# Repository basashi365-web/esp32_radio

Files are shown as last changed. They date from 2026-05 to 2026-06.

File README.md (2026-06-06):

# ESP32 Radio

`esp32_radio` は、完成済みの `pi_radio` を小型ESP32-S3機へ派生させるためのネットラジオ実験プロジェクトです。

目標は、ESP32-S3 + MAX98357A I2Sアンプで WNYC / BBC / ABC のニュース・トーク局を再生し、後段でOLED表示、KY-040ロータリー操作、Wi-Fi設定画面を追加できる設計にすることです。

## 現在の状態

- PlatformIO初期ファームウェア実装済み。COM24へ書き込み、ESP32-S3 / PSRAM / OLED / Wi-Fi / WNYC音出しまで実機確認済み。
- GitHub repository: https://github.com/basashi365-web/esp32_radio
- 第一候補ライブラリは `schreibfaul1/ESP32-audioI2S`。
- ESP32-S3はPSRAM付きボードを前提にする。今回使う実物基板は写真上で `ESP32-S3-WROOM-1 N16R8` と確認済み。
- スピーカーは購入済みの 2インチ級 / 53mm / 4Ω / 3W フルレンジスピーカーを使う。
- 表示器は `pi_radio` と同じ GM009606v4.3 OLED を使い、`SSD1306 128x64 / I2C 0x3C` として扱う方針。
- 基板・周辺部品の共有写真は `D:\data\codex\shared_assets\hardware\esp32_radio\20260601_board_photos` に保存済み。
- MAX98357AとのI2S接続、候補局URL、OLED/ロータリー追加方針、Wi-Fi設定方式を調査済み。
- MAX98357Aは `VIN=5V`、`SD/MODE=3.3V` で音出し確認済み。GAINはオープンのまま。
- OLEDはI2C `0x3C` で検出済み。FreeSans系フォントの局名/音量表示を採用済み。
- KY-040は回転で音量、短押しで選曲。常用版は WNYC / BBC / ABC の3局トグル。
- 友人へ渡す将来構想として、ESP32-S3のUSB MSC設定モードで `WIFI.TXT` / `STATIONS.TXT` をPCから編集できる方式を後段候補にする。
- `pi_radio` との差分は、Linux/mpv/systemd/NetworkManagerではなく、ESP32ファームウェア単体で再生・操作・設定保存を行う点。

## 主要ドキュメント

- `docs/esp32_i2s_radio_research.md`: ESP32-S3 + MAX98357Aネットラジオの前例調査、リスク、最小実験手順。
- `docs/hardware.md`: 想定ハードウェアと部品選定。
- `docs/wiring.md`: 初期配線案。
- `docs/setup.md`: 次回の最小実験セットアップ入口。
- `docs/troubleshooting.md`: 実装前に想定している失敗パターン。
- `docs/development_notes.md`: 継続作業メモ。
- `docs/usb_msc_config_plan.md`: USB接続でTXT設定を編集する将来構想。

## 最小実験方針

1. PSRAM付きESP32-S3ボードを確認する。
2. MAX98357AをI2S 3線で接続する。
3. 53mm / 4Ω / 3W フルレンジスピーカーを `SPK+` / `SPK-` に接続する。
4. `ESP32-audioI2S` の初期スケッチでWNYC MP3直ストリームを再生する。
5. OLEDへ大きい局名、中サイズの音量、小さい `tuning...` / `stream ok` / `stream lost` を出す。
6. KY-040で音量変更と選曲を行う。
7. 友人配布向けには、Web設定画面またはUSB MSC TXT設定モードを後段で検討する。

## 参考元

- `pi_radio`: Raspberry Pi 3B+ + USB DAC/PAM8403で完成済みの親プロジェクト。
- `schreibfaul1/ESP32-audioI2S`: ESP32-S3 + I2S DAC/amp向けの第一候補ライブラリ。
- `Edzelf/ESP32Radio-V2`: 完成型ESP32ラジオUI/設定機能の参考。

## 注意

- Wi-Fi SSID/passwordなどの秘密情報はこのrepoに入れない。
- HLS/AAC局はPC上で音声検出できても、ESP32実機での再生は未確認。
- PSRAMなしESP32-S3での動作は前提にしない。

## Wake Sound

- KY-040長押し停止から復帰するとき、OLED下段に `wake...` を出し、SPIFFS上の `data/wake.m4a` を音量15で短く鳴らす。
- 音源は `D:\data\codex\shared_assets\sound_packs\skysea_sound_pack\reserve_notice.m4a` を採用した。
- 効果音ファイルを更新した場合は、通常の `pio run -t upload` に加えて `pio run -t uploadfs` も実行する。
- 2026-06-02時点では `pi_radio` のスピーカーを流用中。注文済みスピーカー到着後、起動時音量と復帰効果音音量を再調整する。

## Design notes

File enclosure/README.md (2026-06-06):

# ESP32 Radio Enclosure

`esp32_radio_compact.scad` is a first compact enclosure draft for the arrived
53 mm speaker.

## Layout

Front face, left to right:

1. KY-040 knob
2. 53 mm full-range speaker
3. SSD1306 128x64 OLED

The initial outside size is `145 x 78 x 48 mm`. This keeps the radio compact
while leaving room for the speaker depth, OLED board, KY-040 body, ESP32-S3,
MAX98357A, and wiring.

## Parts

- Front shell: set `part_mode = 1;`
- Back cover: set `part_mode = 2;`
- Preview both: set `part_mode = 0;`

## Measure Before Final Print

Tune these parameters after checking the actual parts:

- `speaker_outer_d`: actual speaker outside diameter
- `speaker_cutout_d`: full round opening diameter; current draft uses `47`
- `speaker_grille_enabled`: keep `false` when no protective grille is needed
- `speaker_mount_holes_enabled`: keep `false` when using the rear support ring
- `speaker_screw_circle_d`: speaker screw pitch circle
- `speaker_screw_hole_d`: screw hole diameter
- `encoder_shaft_hole_d`: knob shaft hole
- `encoder_mount_spacing`: KY-040 board mounting pitch
- `oled_window_w` / `oled_window_h`: visible OLED window
- `oled_board_w` / `oled_board_h`: OLED PCB size
- `oled_screw_spacing_x` / `oled_screw_spacing_y`: OLED mounting holes

## Print Notes

- Print the front shell face down if the printer handles bridge holes cleanly.
- Print the back cover flat.
- First print a thin front-panel-only test or use slicer preview to confirm the
  knob, speaker, and OLED positions before committing to a full enclosure.
- Keep Wi-Fi credentials and local configuration outside public CAD/docs.

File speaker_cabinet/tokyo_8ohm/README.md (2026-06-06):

# Tokyo Cone 8 Ohm Speaker Cabinet

This folder stores the cabinet work for the Tokyo Cone F12E28A01-1 oval speaker.

## Speaker

- Model: F12E28A01-1
- Type: 30 x 70 mm oval speaker
- Impedance: 8 ohm
- Use here: low-profile ESP32 radio integrated cabinet

## Main Files

- `esp32_radio_low_profile_integrated.scad`
- `esp32_radio_low_profile_front_shell.stl`
- `esp32_radio_low_profile_back_cover.stl`
- `esp32_radio_low_profile_front_layout.png`
- `datasheets/F12E28A01-1_speaker_datasheet.pdf`

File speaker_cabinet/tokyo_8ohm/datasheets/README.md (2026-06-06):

# Speaker Datasheets

This folder stores datasheets for speakers used while designing the ESP32 radio speaker cabinet.

## F12E28A01-1

- File: `F12E28A01-1_speaker_datasheet.pdf`
- Original downloaded file: `C:\Users\yuko\Downloads\スピーカー仕様書F12E28A01-1.pdf`
- Stored on: 2026-06-04
- Use: reference for the 4 ohm speaker cabinet dimensions and acoustic notes.

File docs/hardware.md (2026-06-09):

# Hardware Notes

## 目的

`esp32_radio` の初期実験では、Raspberry Piを使わずにESP32-S3単体でネットラジオを鳴らせるかを確認する。

## 初期候補

| 部品 | 用途 | 状態 |
|---|---|---|
| ESP32-S3-WROOM-1 N16R8 開発ボード | Wi-Fi受信、デコード、I2S出力 | 実物写真確認済み |
| MAX98357A I2S Class-D mono amp | I2S DAC内蔵アンプ | 初期音声出力 |
| 2インチ級 / 53mm / 4Ω / 3W フルレンジスピーカー | 音声出力 | 購入済み。MAX98357Aの初期実験用 |
| 5V USB電源 | ESP32-S3とアンプ給電 | 電流余裕を確認 |
| GM009606v4.3 OLED | 状態表示 | Phase 2以降。`pi_radio` と同じ表示器 |
| KY-040ロータリーエンコーダ | 音量/局切替 | Phase 3以降 |

## 18650電池化の手持ち候補

2026-06-06に、手持ち部品写真から以下を電池駆動の試作候補として選ぶ。

| 部品 | 写真上の識別 | 用途 | 判断 |
|---|---|---|---|
| XL6009E1昇圧モジュール | `XLSEMI XL6009E1`、青基板、可変抵抗付き | 18650の3V台を5Vへ昇圧 | 手持ち昇圧モジュールがこれ1個のため試作に使う。ESP32接続前に必ずテスターで5.0V前後へ調整する |
| 緑TP4056 USB-C基板 | `4056E`、`DW01A`、`8205A`、`B+` / `B-` / `OUT+` / `OUT-` 表記 | 1S Li-ion充電と保護出力 | 青TP4056より良い候補。保護IC付きに見え、電池端子と負荷端子が分かれているため試作ではこちらを使う |
| 青TP4056 micro USB基板 | `TP4056`、`4056E`、`BAT+` / `BAT-` 表記 | 1S Li-ion充電 | 充電専用基板に見える。保護付き18650を使う場合以外は今回の内蔵試作では優先しない |

この構成はpower pathではない。まずは「電源OFFで充電し、使用時は充電USBを外す」運用で試す。充電しながら常用する完成版にする場合は、load sharing / power path対応の1S充電昇圧モジュールを別途検討する。

## 18650電池化の購入済み候補

2026-06-06に、AliExpressで1S Li-ion用の充放電統合モジュールを購入した。到着予定は2026-06-10から2026-06-12。

| 部品 | 用途 | 状態 | 注意 |
|---|---|---|---|
| 1S Li-ion充放電統合モジュール Type-C / 5V 2A | 18650充電、5V昇圧、充電しながらの放電 | 5個購入済み。到着予定 2026-06-10から2026-06-12 | 通常18650では4.2V充電設定で使う。50mA未満の軽負荷で出力OFFになる仕様のため、stopped待機中の挙動を実測する |

購入時スクリーンショットと仕様メモは共有資産へ保存した。

- `D:\data\codex\shared_assets\hardware\esp32_radio\20260606_battery_power_module`

## 実物写真

今回使う基板・周辺部品のトリミング済み写真は、他プロジェクトからも参照できる共有フォルダに保存した。

- `D:\data\codex\shared_assets\hardware\esp32_radio\20260601_board_photos`
- 元写真: `C:\Users\yuko\Desktop\FTP\20260601_*.jpg`
- 共有用写真: ESP32-S3 N16R8表裏、MAX98357A表裏、I2C OLED表裏、KY-040、コンタクトシート。
- 完成写真: `D:\data\codex\shared_assets\hardware\esp32_radio\20260607_completed_battery_radio`

ESP32-S3基板のモジュール刻印は写真上で `ESP32-S3-WROOM-1 N16R8` と読める。以前の Freenove ESP32-S3 Cam とは別個体として扱う。

## 完成後の筐体改善メモ

- 電源スイッチ穴は実機では超音波カッターで後加工した。次回の3Dプリント筐体では、電源スイッチ位置を確定して最初から穴を入れる。
- USB充電口も次回の3Dプリント筐体で最初から穴を入れる。現行TP4056のUSB-C、または将来の1S Li-ion充放電統合モジュールのType-C入力へアクセスできる位置にする。
- OLED右下がスピーカー側と干渉したため、実機ではディスプレイ基板を少し切り取って逃がした。次回はOLEDをもう少し左へ寄せ、スピーカーとのクリアランスを増やす。

## 現在の運用状態

2026-06-07時点では、TP4056 + XL6009E1 + 18650構成を実稼働状態として扱う。パススルー対応の1S Li-ion充放電統合モジュール到着までは、この構成で運用する。

運用ルール:

- 充電時はラジオ電源OFF。
- 使用時は充電USBを外す。
- バッテリー残量はGPIO1分圧ADCでOLEDへ表示する。

## ESP32-S3

`ESP32-audioI2S` はPSRAMを必要とするため、PSRAM付きESP32-S3を前提にする。今回の実物写真では `ESP32-S3-WROOM-1 N16R8` の刻印を確認したため、初期実験の第一候補はこのボードにする。

推奨:

- ESP32-S3-N8R8
- ESP32-S3-N16R8
- ESP32-S3-WROOM-1-N16R8

次回確認すること:

- 実ボードの型番は写真上では `ESP32-S3-WROOM-1 N16R8`。PlatformIO/Arduino側からもFlash/PSRAM認識を確認する。
- USB/JTAGや起動ストラップと競合しないGPIO。
- ネイティブUSB Deviceを使える配線/USBポートか。

## MAX98357A

MAX98357AはI2S入力を受けるモノラルClass-Dアンプ。初期実験では1個だけ使い、左右mixまたは片ch出力で小型スピーカーを鳴らす。

注意:

- `SPK+` / `SPK-` はBTL出力で、どちらもGNDへ接続しない。
- 大音量では電流不足によるリセットや音割れが起きやすい。
- GAINとSD/MODEはまずモジュール既定で試す。

## スピーカー

購入済み:

- 2インチ級 / 53mm フルレンジスピーカー。
- 定格インピーダンス: 4Ω。
- 定格出力: 3W。
- 4個セット。

MAX98357Aは3W級のモノラルClass-Dアンプなので、初期実験の組み合わせとして適している。
最初は音量を低めにし、音割れ、ビビり、ESP32-S3のリセットが出ないか確認する。

商品画像から読み取った寸法・仕様:

| 項目 | 値 |
|---|---|
| 正面外形 | 約52.6mm |
| 直径表記 | 53mm |
| 側面幅表記 | 約39.4mm |
| 側面高さ表記 | 約28.5mm |
| 高さ表記 | 30mm |
| 形状 | 円形 |
| 定格出力 | 3W |
| 定格インピーダンス | 4Ω |
| 周波数応答 | 商品画像では `170kHz` 表記。一般的な小型スピーカー仕様としては要再確認 |
| 感度 | 100 dB/W |
| 信号対雑音比 | 商品画像では `1dB` 表記。スピーカー仕様としては要再確認 |
| 高調波歪み | 商品画像では `1 TMD%` 表記。THD表記の可能性があるため要再確認 |

注意:

- スピーカーは `SPK+` / `SPK-` に接続する。
- `SPK-` をGNDへ落とさない。
- 2個のMAX98357Aでステレオ化する案もあるが、最初は1個のモノラルで十分。
- 商品ページ由来の周波数応答や歪み表記は不自然な可能性があるため、設計では4Ω / 3W / 約53mmの実装寸法を優先する。

## pi_radioから引き継ぐ考え方

- 常用局は WNYC / BBC Radio 4 / ABC NewsRadio の3局にする。NHK R1は配信方式変更と暗号化HLSの可能性があるため、操作UIには出さない。
- OLEDには局名、状態、IP、音量を出す。
- OLEDは `pi_radio` と同じ GM009606v4.3 を使い、`SSD1306 128x64 / I2C 0x3C` として扱う。
- ロータリーは回転で音量、短押しで局切替を基本にする。

移植しないもの:

- Linux systemd。
- NetworkManager。
- `shutdown -h now` による安全停止。
- USB DAC / PAM8403 構成。

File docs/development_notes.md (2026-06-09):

# Development Notes

## 2026-05-30

- `esp32_radio` を `pi_radio` 派生の本格プロジェクトとして扱う方針になった。
- 実装前に `docs/esp32_i2s_radio_research.md` を作成した。
- 最小実験の第一候補は `schreibfaul1/ESP32-audioI2S`。
- PSRAM付きESP32-S3を前提にする。
- WNYCはMP3直ストリームとして最初に試す。
- BBC Radio 4 / ABC NewsRadio / NHK R1 はPC上の `ffprobe` でHLS/AAC音声として検出できたが、ESP32実機再生は未確認。
- Web設定画面は初期実験には入れず、再生安定後の追加候補にする。
- 表示器は `pi_radio` と同じ GM009606v4.3 OLED を使う方針。`SSD1306 128x64 / I2C 0x3C` として扱う。
- 友人へ渡す将来構想として、ESP32-S3のUSB MSC設定モードでPCから `WIFI.TXT` / `STATIONS.TXT` を編集する方式を最後に試す候補へ追加した。
- スピーカーは購入済みの2インチ級 / 53mm / 4Ω / 3Wフルレンジスピーカーを使う。商品画像上の寸法は正面外形約52.6mm、直径53mm、高さ30mm。

## 次回作業入口

1. PlatformIO/Arduino側でPSRAM容量を確認する。
2. 53mm / 4Ω / 3WスピーカーをMAX98357Aへ接続する。
3. `platformio.ini` のボード/PSRAM設定が実機に合うか確認する。
4. MAX98357A + WNYC の最小再生スケッチをCOM24へ書き込む。
5. Serialログと実機結果をこのdocsへ追記する。
6. 再生とOLED/ロータリーが安定した後、USB MSC TXT設定モードを調査する。

## 2026-06-01 実機接続メモ

- ESP32-S3 N16R8 dev board はWindows上で `COM24` として見えている。COMポートは接続順で変わるため、実験前に再確認する。
- Wi-Fiは固定SSIDではなく、ローカル設定のSSID prefixで候補を絞る。
- 複数SSIDがある環境では、単純なRSSI最強ではなく、前回成功SSIDをESP32 Arduino `Preferences` に保存して次回起動時に優先する。
- 接続成功SSIDは `Preferences` namespace `wifi` / key `last_ssid` に保存する設計にする。
- 実パスワードは `include/config.local.h` のみに置き、repoやAI Docsへ入れない。
- PlatformIO最小プロジェクトを追加した。`src/main.cpp` はPSRAM/Flash情報をSerialへ出し、SSID prefix一致候補から前回成功SSIDを優先してWi-Fi接続し、WNYCをMAX98357AへI2S出力する初期スケッチ。
- 標準PlatformIO `espressif32` では `ESP32-audioI2S` 3.4.6 が `<span>` を要求してビルド失敗したため、`pioarduino/platform-espressif32` stableへ切り替えた。
- `ESP32-audioI2S` 3.4.6 の `Audio.h` が `std::optional` を使うが `<optional>` を直接includeしていないため、`platformio.ini` の `build_flags` で `-I include` と `-include optional` を追加した。Cファイルにも同じflagが当たるため、`include/optional` にC++時だけ本物の標準ヘッダへ渡す小さなshimを置いた。
- USBケーブル交換後、`pio run -t upload` がCOM24へ成功した。低速 `upload_speed = 115200` と `PYTHONIOENCODING=utf-8` / `PYTHONUTF8=1` を使うとPlatformIOの進捗文字によるcp932例外を避けやすい。
- SerialログでESP32-S3 rev 2、Flash 16MB、PSRAM 8MBを確認した。
- Wi-Fiはprefix一致候補を見つけ、`Preferences` の前回成功SSID優先で接続成功した。
- OLEDとKY-040が接続済みになったため、初期スケッチへSSD1306 OLED表示、I2C scan、KY-040音量変更、短押し局送りを追加した。
- 実機ログでOLEDはI2C `0x3C` として検出できた。
- WNYCはSSL接続、MP3Decoder初期化、`stream ready`、MPEG-1 Layer III / 32kHz / 96kbps まで確認できた。実音声はスピーカー側で要耳確認。
- KY-040の回転で音量変更ログを確認できた。短押し局送りもログ上は動いている。
- BBC Radio 4の旧HLS URLは実機で `HTTP/1.1 410 Gone`。2026-06-02時点で見つかるnon-UK向けHLS URLへ差し替えた。
- NHK R1は候補URLでDNS失敗が一度出た。再テストが必要。
- 2026-06-02: KY-040の音量表示は素直に反応。ABC Newsへ移動したところで長時間ブロックし、その後NHKへ移ったとの実機報告あり。音出しが終わるまでHLS局は局送り対象から外し、WNYCだけを有効化する。
- スピーカーから音が出ていない。GAINはオープンで問題なし。SD/MODEもオープンだったため、まずSD/MODEを3.3Vへ接続して強制ONで確認する。
- OLED表示は、局名を上半分の大きい文字、音量を中くらい、ストリーム/IP状態を最下段の小さい文字に変更した。
- OLEDの局名/音量表示をAdafruit GFXのFreeSans系フォントへ変更した。白黒OLEDなので本当のアンチエイリアスはないが、デフォルトフォントより読みやすい字形にする。
- 最下段は `bitrate...` などの内部イベント名を出さず、再生準備ができたら `stream ok` を出す。
- WNYCが時々無音になるとの報告。ログ上は `slow stream, dropouts are possible` が出ていたため、ストリーム停止/再接続とアンプ側無音を切り分ける必要がある。`audio.isRunning()` を監視し、停止が続く場合はOLED下段に `stream lost`、再接続時は `stream ok` を出す。
- OLEDフォントはFreeSans系で確定。最下段は内部イベント名を出さず、人間向けの `tuning...` / `stream ok` / `stream lost` / `not tested` だけにする。
- KY-040クリックは選曲操作にする。未検証局は局名表示だけ切り替え、再生は開始しないことでABC/NHKの長時間ブロックを避ける。
- BBC Radio 4はBBCだけ有効化した実機テストで音出しOK。WNYCのMP3直ストリームだけでなく、少なくともBBCのHLS入口はESP32-S3 + ESP32-audioI2S + MAX98357A構成で再生できる。
- 次は同じ手順でABC NewsRadioだけを追加有効化し、フリーズ/無音/`stream ok` を確認する。
- ABC NewsRadioは `stream ok` までは到達。ただし実音声は出なかった。深夜帯の無音、局側の番組状態、またはHLS/AACの音声処理差を疑い、後日別時間帯でも再確認する。
- 次はNHK R1を追加有効化し、同じく `stream ok` と実音声を切り分ける。
- ABC表示中にクリックすると、次局へ移るまで約10秒停止する。NHK R1は `tuning...` で止まり、その後クリック/音量操作も効かない完全フリーズへ進んだ。初期常用版ではABC/NHKを再び無効化し、WNYC/BBCだけを有効局にする。
- ABC/NHKは夜間の局側状態だけでなく、`audio.connecttohost()` またはHLS処理がブロックしてUIループを止めるリスクがある。再検証は別時間帯に、まずSerialログを取りながら1局ずつ行う。
- 2026-06-02朝にABC/NHKを再度有効化して実機確認した。ABCは音が出ず、10秒以上フリーズする。NHKも音が出ず、最終的に完全フリーズする。時間帯だけの問題ではなく、ESP32側の接続/デコード処理がUIループを巻き込む問題として扱う。
- 常用版はWNYC/BBCのみ有効、ABC/NHKは `not tested` 表示だけに戻す。ABC/NHKを再検証する場合は、同期的な `audio.connecttohost()` を直接UIループで呼ばない設計、またはタイムアウト/別タスク化を先に検討する。
- 2026-06-02朝の再調査で、esp32_radioに入れていたABC URL `2038310/.../master.m3u8` はPC側でも404だった。pi_radio実績のABC URL `2038311/.../index.m3u8` は `streaming.abc-cdn.net.au` へリダイレクトし、AAC音声として検出できた。
- ESP32実機ではABCをmaster playlistではなくAAC-LC 44.1kHz monoのmedia playlist `https://mediaserviceslive.akamaized.net/hls/live/2109425/newsradio/v0-221.m3u8` へ直結したところ音出し成功。WNYC/BBC/ABCは常用局として有効化する。
- `audio.setConnectionTimeout(1000, 2500)` を追加し、`connecttohost()` の経過時間をSerialへ出すようにした。これ以降、ABC/NHKを触っても全体フリーズは出ず、選局操作はスムーズになった。
- NHK R1はpi_radio実績URL `https://simul.drdi.st.nhk/live/3/joined/master.m3u8` がPC側でAAC/HLSとして検出できるが、media playlistに `EXT-X-KEY:METHOD=AES-128` が含まれる。ESP32-audioI2S側で暗号化HLSが扱えない可能性があるため、現時点では常用局から外して `not tested` 扱いに戻す。
- moriya判断でNHK R1は表示にも出さず、常用版はWNYC/BBC/ABCの3局トグルにする。NHKは今後の研究対象としてdocsには履歴を残すが、操作UIからは外す。

## 音質検討メモ

- `pi_radio` と比べると `esp32_radio` は少し音が悪い気がしたが、現時点では決定的な差とは判断しない。
- 同じスピーカーを流用しているため、主な差分要因は MAX98357A、5V/GND配線、電源安定性、ESP32側のWi-Fi/デコード負荷、I2S処理まわりと考える。
- MAX98357Aの `SD/MODE` を3.3Vへ接続したら音が出た。`SD/MODE` オープンは今回の無音原因だった可能性が高い。
- `GAIN` はオープンでよい。音割れやノイズが出た場合だけ、GAIN設定、ソフト音量、電源容量を見直す。
- `PCM5102A + PAM8403` は音質改善候補。ただし部品、配線、電源、筐体内スペース、コストが増え、今回はチリツモになるため保留する。
- 現時点では MAX98357A 構成を採用継続する。
- 音質改善はまず、筐体、スピーカー固定、5V/GND配線の太さ/短さ、電源安定化、I2S配線の取り回しから見る。
- WNYCの無音化は、OLED下段表示とSerialログで `stream` 側か I2S/アンプ側かを切り分ける。`stream ok` のまま無音ならI2S/アンプ/電源側、`stream lost` や再接続表示ならネットワーク/ストリーム側を疑う。

## 通信停止/待機メモ

- スマホのテザリング利用時に消し忘れで通信し続けるのを避けるため、KY-040長押しでESP32向けの停止状態へ入る。
- 停止時は `audio.stopSong()`、`WiFi.disconnect(false)`、`WiFi.mode(WIFI_OFF)` を行い、OLEDの音量表示位置に `stopped`、下段に `wifi off` を表示する。
- 停止中は `audio.loop()` と自動リトライを止める。
- 停止中にKY-040を回す、または押すと復帰する。復帰操作そのものは音量変更や局送りには使わず、まずWi-Fi再接続と現在局の再生を試す。
- これは `pi_radio` のshutdownではなく、ESP32版の通信停止/待機機能として扱う。
- 実機で長押し停止と、KY-040を回す/押す操作による復帰が成功した。
- 2026-06-02: stoppedからの復帰時に遊びとして効果音を追加した。`skysea_sound_pack` の3候補から、短く軽い `reserve_notice.m4a` を選び、`data/wake.m4a` としてSPIFFSへ格納する。
- 復帰時はOLED下段に `wake...` を出し、効果音だけ `WAKE_EFFECT_VOLUME=15` で再生する。再生後は元の `currentVolume` に戻し、Wi-Fi再接続と現在局再生へ進む。
- SPIFFSは `board_build.filesystem = spiffs` と `pio run -t uploadfs` で書き込む。ファーム本体とは別領域なので、効果音を変えた場合は `uploadfs` も必要。

## 仮完成メモ

- 2026-06-02時点で、ESP32-S3 + MAX98357A + OLED + KY-040 による WNYC / BBC / ABC の3局トグル版はひとまず完成扱いにする。
- 現在のスピーカーは `pi_radio` のものを流用中。注文済みの 53mm / 4Ω / 3W スピーカー到着後、2026-06-05ごろを目安に音量を再調整する。
- 次回調整対象は、起動時の `AUDIO_VOLUME_INITIAL` と、stopped復帰効果音の `WAKE_EFFECT_VOLUME`。現時点の復帰効果音は volume 15。

## 18650電池化メモ

- 2026-06-06: 18650内蔵案を検討した。2S直列は電源余裕があるが、2セル用の充電制御/BMSが手元にないため今回は保留する。
- 1S2P並列は心理的に避けたい方針。今回の試作では使わない。
- 手持ち部品では、緑TP4056 USB-C基板とXL6009E1昇圧モジュールを候補にする。緑TP4056は写真上で `B+` / `B-` / `OUT+` / `OUT-` があり、`DW01A` / `8205A` 保護回路付きに見えるため、青TP4056より今回向き。
- この構成はpower pathではない。充電しながら鳴らす常用は避け、まずは電源OFFで充電、使用時は充電USBを外す運用で試す。
- OLEDへ電池残量%を出す場合は、昇圧後の5Vではなく18650側を抵抗分圧してADCで読む。
- 2026-06-06: 1S Li-ion充放電統合モジュール Type-C / 5V 2A をAliExpressで5個購入した。到着予定は2026-06-10から2026-06-12。購入時スクリーンショットは `D:\data\codex\shared_assets\hardware\esp32_radio\20260606_battery_power_module` に保存した。
- 商品説明上は、充電しながらの放電に対応、昇圧出力5Vから5.15V / 2A、負荷50mA未満継続で出力OFF、K端子で出力ON/OFF可能。到着後は、再生中の5V低下、USB抜き差し時の瞬断、stopped待機中の自動OFF、発熱を確認する。
- 2026-06-07: TP4056 + XL6009E1を筐体内へ配置し、デバイス動作を確認した。GPIO1へ100kΩ/100kΩ分圧を入れ、OLED右下へ `Bxx%` として18650残量目安を表示するファームウェアをCOM24へ書き込んだ。
- 電源投入時に起動しているようでもOLEDが点灯しないことがあるため、OLED初期化を3回試行し、起動後も未検出なら3秒ごとに再初期化する処理を追加した。
- バッテリー表示は実機で動作確認できた。GPIO1とGNDの間に10uFセラミックコンデンサを追加したところ、コンデンサなしに比べてADC由来の表示ふらつきがかなり減り、残量表示が実用上落ち着いた。表示更新を約7秒ごと、1%以内の変化は前回表示維持にして、OLED表示のちらつきをさらに抑える方針にした。
- 2026-06-07: バッテリー運用版として完成。USBケーブルから解放されることで、ラジオデバイスとしての使い心地がかなり良くなった。完成写真は `D:\data\codex\shared_assets\hardware\esp32_radio\20260607_completed_battery_radio` に保存した。写真上では WNYC FM / Vol 3 / battery 53% / `stream ok` が表示されている。
- 完成後の筐体改善点: 電源スイッチ部分は実機では超音波カッターで後加工して穴を開けたため、次回筐体設計では最初から電源スイッチ穴を入れる。USB充電できるように、TP4056または将来の充放電統合モジュールのUSB充電口用の穴も最初から入れる。OLED右下がスピーカー側と干渉し、実機ではディスプレイ基板を少し切り取って逃がしたため、次回はOLED位置をもう少し左へ寄せてスピーカーとの干渉余裕を取る。
- 現在の状態: パススルー対応の1S Li-ion充放電統合モジュールが届くまでは、TP4056 + XL6009E1 + 18650構成を実稼働状態として運用する。充電時はラジオ電源OFF、使用時は充電USBを外す運用を継続する。

## 記録ルール

- 実機で確認したことは、未確認仮説と分けて書く。
- Wi-Fiパスワード、トークン、APIキーは書かない。
- 放送局URLは変更される可能性があるため、確認日を書く。
- `pi_radio` から再利用した設計と、ESP32用に変えた設計を分ける。

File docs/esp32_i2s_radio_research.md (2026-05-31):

# ESP32-S3 + MAX98357A I2S Radio Research

作成日: 2026-05-30

このメモは、`pi_radio` の派生版として ESP32-S3 + MAX98357A による小型ネットラジオ `esp_radio` を設計するための事前調査である。まだ実装は始めない。前例、部品構成、リスク、最小実験手順を整理する。

## 結論

- 最小実験の第一候補は `schreibfaul1/ESP32-audioI2S`。
- ESP32-S3は PSRAM付きボードを前提にする。特に `ESP32-S3-N16R8` や `N8R8` のような PSRAM搭載品が安全。
- MAX98357Aは I2S 3線 `BCLK` / `LRC` / `DIN` と電源/GNDだけで音が出せる。モノラルアンプなので、まずは1個で十分。
- スピーカーは購入済みの2インチ級 / 53mm / 4Ω / 3Wフルレンジスピーカーを使う。
- `WNYC` はMP3直ストリームなので最も実験向き。
- `BBC Radio 4`、`ABC NewsRadio`、`NHK R1` はHLS/AACとしてPC上では音声検出できたが、ESP32実機では `m3u8` リダイレクト、TLS、バッファ、地域/配信URL変更のリスクがある。
- Web設定画面は最初から本格実装しない。最初は固定SSID + 固定局URLで音を出し、次に簡易AP/設定保存、最後にWeb UIを検討する。
- 友人へ渡す段階では、ESP32-S3のUSB MSC設定モードでPCから `WIFI.TXT` / `STATIONS.TXT` を編集できる方式を後段候補にする。
- `Edzelf/ESP32Radio-V2` は完成度の高いラジオアプリの参考にはなるが、最小実験の土台としては大きい。`esp_radio` では `ESP32-audioI2S` を使った薄い実装から始める方が `pi_radio` の派生として管理しやすい。

## 調査対象

### schreibfaul1/ESP32-audioI2S

リポジトリ:

- https://github.com/schreibfaul1/ESP32-audioI2S
- Wiki: https://github.com/schreibfaul1/ESP32-audioI2S/wiki

確認した内容:

- ESP32、ESP32-S3、ESP32-P4対応。
- PSRAM最小2MBが必要と明記されている。
- 外部DACが必要で、MAX98357Aがテスト済みDACに含まれる。
- 対応codecは MP3、AAC、AAC+、WAV、FLAC、Vorbis、M4A、Opus。
- `pls`、`m3u`、`asx`、`m3u8` プレイリストを認識するとされる。
- Wi-Fi、SD、SD_MMC、SPIFFS、FFatが音源に使える。
- サンプルは `audio.setPinout(I2S_BCLK, I2S_LRC, I2S_DOUT)` でI2Sピンを指定し、`audio.connecttohost(url)` でストリームへ接続する。

評価:

- `esp_radio` の最小実験に向く。
- MAX98357Aと直接組み合わせやすい。
- HLS/AACまで試せる可能性がある。
- PSRAM必須なので、手元ボードの型番確認が最初の関門。

### Edzelf/ESP32Radio-V2

リポジトリ:

- https://github.com/Edzelf/ESP32Radio-V2

確認した内容:

- 旧 `ESP32-Radio` の新バージョン。
- I2S出力と SP/DIF 出力に対応。
- `config.h` でコンパイル時設定を行う。
- `data` ディレクトリのアップロードが必要。
- SDカード対応は experimental。
- 2024-10-17にESP32-S3実験対応が入っている。
- `DEC_HELIX` 系を選ぶとMP3/AACのソフトウェアデコード + I2S出力構成になる。
- OLED、TFT、Nextion、ロータリーエンコーダ、MQTT、Web設定など、完成品ラジオ寄りの機能を多く持つ。

評価:

- 完成形のUI、設定、Web画面、ロータリー入力、プリセット管理の参考にする価値が高い。
- 一方で、最初の `音が出るか` 実験には大きすぎる。
- `esp_radio` の第一段階では採用せず、第二段階以降の設計参考にする。

### Edzelf/ESP32-Radio

リポジトリ:

- https://github.com/Edzelf/ESP32-Radio

確認した内容:

- README上でV2の利用が推奨されている。
- 古い版はVS1053 + TFT中心の構成。
- MP3/Ogg、`.m3u`、最大320kbps、Web設定、内蔵Webサーバ、MQTT、シリアル、IR、ロータリー、タッチ入力などの機能がある。

評価:

- 旧版は設計思想と機能一覧の参考に留める。
- 新規派生の直接ベースにはしない。

## PSRAM付きESP32-S3が必要か

必要と考える。

理由:

- `ESP32-audioI2S` は現行README/Wikiで PSRAM必須を明記している。
- WebラジオではWi-Fi受信、HTTP/HLS処理、codec decode、I2S出力を同時に行うため、バッファ不足が音切れやクラッシュに直結する。
- `pi_radio` と違い、ESP32側ではLinux/mpvの大きな余裕がない。

推奨:

- 最小: ESP32-S3 + PSRAM 2MB以上。
- 推奨: ESP32-S3 + PSRAM 8MB以上。
- 候補表記: `ESP32-S3-N8R8`、`ESP32-S3-N16R8`、`ESP32-S3-WROOM-1-N16R8` など。

確認方法:

- 購入ページや基板シルクで PSRAM有無を確認する。
- PlatformIO/Arduinoの起動ログで `PSRAM` 検出を確認する。
- 実験スケッチで `ESP.getPsramSize()` を表示する。

## MAX98357AとのI2S配線

MAX98357A側の主要ピン:

| MAX98357A | 役割 | ESP32-S3側 |
|---|---|---|
| VIN | 電源 | 5V推奨。小音量実験なら3.3Vでも動く場合がある |
| GND | GND | GND共通 |
| BCLK | I2S bit clock | 任意の出力可能GPIO |
| LRC / LRCLK / WS | I2S left/right clock | 任意の出力可能GPIO |
| DIN | I2S audio data in | 任意の出力可能GPIO |
| SD / MODE | shutdown / L/R/mono選択 | まずはモジュール既定。必要なら抵抗でmono平均を確認 |
| GAIN | gain設定 | まずは未接続またはモジュール既定 |
| SPK+ / SPK- | スピーカー出力 | 4Ω以上の小型スピーカー。GNDへ接続しない |

初期配線案:

| 信号 | ESP32-S3 GPIO案 | 備考 |
|---|---:|---|
| I2S_DOUT -> DIN | GPIO4 | `ESP32-audioI2S` Wiki例に合わせた案 |
| I2S_BCLK -> BCLK | GPIO5 | 同上 |
| I2S_LRC -> LRC | GPIO6 | 同上 |
| OLED SDA | GPIO8 | 仮。実ボードの空きピンに合わせて変更 |
| OLED SCL | GPIO9 | 仮。実ボードの空きピンに合わせて変更 |
| Rotary A | GPIO10 | 仮。割り込み入力に使いやすいピン |
| Rotary B | GPIO11 | 仮 |
| Rotary SW | GPIO12 | 仮。内部pull-up利用想定 |

注意:

- ESP32-S3は基板ごとに使えないピンやUSB/JTAG/PSRAM/Flashに近い注意ピンがある。実ボード型番確定後にピン表で再確認する。
- MAX98357Aのスピーカー出力はBTL出力なので、`SPK-` をGNDへ落とさない。
- 大音量では電流が増えるため、スピーカー駆動は5V電源に余裕を持たせる。
- 音割れやノイズが出る場合、GAINを下げる、音量初期値を下げる、BCLK/LRC/DINの配線を短くする。
- 今回の初期スピーカーは2インチ級 / 53mm / 4Ω / 3Wフルレンジ。商品画像上の寸法は正面外形約52.6mm、直径53mm、高さ30mm。MAX98357Aの3W級出力に合うが、最初は音量を低めにする。

## 対応ストリーム形式

`ESP32-audioI2S` ベースで期待できる形式:

| 形式 | 期待度 | 備考 |
|---|---|---|
| MP3直ストリーム | 高 | 最小実験の第一候補 |
| AAC直ストリーム | 高 | ESP32-S3ではAAC+ SBR/Parametric Stereoも対応表に入る |
| PLS / M3U | 中-高 | ライブラリが認識対応。ただしURL解決の癖は実機確認が必要 |
| M3U8 / HLS | 中 | ライブラリ上は認識対象。放送局側のTLS/リダイレクト/セグメント条件で失敗する可能性 |
| Ogg/Vorbis | 中 | 対応表にはあるが、Vorbisはビットレート条件あり |
| FLAC | 低-中 | 対応するが、ネットラジオ用途では負荷・帯域が重い |
| Opus | 中 | 対応表にはあるが、局候補では優先しない |

## 局URLの再生可能性

`pi_radio/config/stations.json` の候補URLをPC上の `ffprobe 8.1.1` で確認した。これは `ESP32で再生できる保証` ではなく、2026-05-30時点でURLが音声ストリームとして見えるかの確認である。

| 局 | URL | PC上の検出結果 | ESP32-S3見込み |
|---|---|---|---|
| WNYC FM | `https://fm939.wnyc.org/wnycfm` | MP3 / 32000Hz / stereo | 最有力。最初に試す |
| BBC Radio 4 | `https://a.files.bbci.co.uk/ms6/live/3441A116-B12E-4D2F-ACA8-C1984642FA4B/audio/simulcast/hls/nonuk/audio_syndication_low_sbr_v1/cfs/bbc_radio_fourfm.m3u8` | HLS / AAC / 48000Hz / stereo | 要実機確認。HLS/TLS/地域条件に注意 |
| ABC NewsRadio | `https://mediaserviceslive.akamaized.net/hls/live/2038311/newsradio/index.m3u8` | HLS / AAC。複数variantあり | 要実機確認。variant選択とHLS処理に注意 |
| NHK R1 | `https://simul.drdi.st.nhk/live/3/joined/master.m3u8` | HLS / AAC / 48000Hz / stereo | 要実機確認。URL変更リスクあり |

最小実験の順番:

1. WNYC MP3直ストリーム。
2. BBC Radio 4 HLS/AAC。
3. NHK R1 HLS/AAC。
4. ABC NewsRadio HLS/AAC。

理由:

- WNYCは `pi_radio` でmpv/systemd再生確認済みで、ESP32側でもMP3直ストリームとして最も単純。
- HLS局は `ESP32-audioI2S` が `m3u8` を認識するとされるが、実機のメモリ、TLS、セグメント取得、リダイレクトの影響を受けやすい。

## OLED表示とロータリーエンコーダ構成

`pi_radio` ではSSD1306 128x64 OLEDとKY-040ロータリーエンコーダで、局名、音量、状態表示、短押し局切替、長押しシャットダウンを扱った。

`esp_radio` での段階案:

### Phase 1: 音だけ

- OLEDなし。
- ロータリーなし。
- 固定SSID、固定URL、Serialログのみ。
- 目的は `ESP32-S3 + MAX98357A + WNYC` で音が出ること。

### Phase 2: 表示

- `pi_radio` と同じ GM009606v4.3 OLEDをI2C接続。
- `pi_radio` では `SSD1306 128x64 / I2C 0x3C` として点灯確認済みなので、`esp_radio` でもまず同じ扱いにする。
- 表示項目:
  - 接続中/再生中/エラー
  - SSIDまたはIPアドレス
  - 局名
  - codec名
  - 音量
  - バッファ状態または再接続回数

### Phase 3: 操作

- KY-040ロータリーエンコーダ追加。
- 回転: 音量。
- 短押し: 次の局。
- 長押し: Wi-Fi設定モード、または停止/再接続。
- ESP32にはOSシャットダウンがないため、`pi_radio` の安全シャットダウン操作はそのまま移植しない。

## Wi-Fi設定方法

候補:

| 方法 | 長所 | 短所 | 推奨段階 |
|---|---|---|---|
| 固定SSID/passwordをビルド時指定 | 最小で確実 | 書き換えに再ビルドが必要。秘密情報をgitに入れない注意が必要 | Phase 1 |
| `WiFiMulti` で複数SSID | 複数環境に少し強い | まだビルド時秘密情報が残る | Phase 1.5 |
| Serial経由で初回設定 | Web UI不要 | 現地運用では不便 | Phase 2候補 |
| SoftAP + Captive Portal / WiFiManager系 | スマホから設定できる | 依存と状態管理が増える | Phase 3候補 |
| USB MSC TXT設定モード | PCとUSBケーブルで `WIFI.TXT` / `STATIONS.TXT` を編集できる。友人配布時に分かりやすい | ESP32-S3専用寄り。PCとESP32の同時書き込みを避ける設計が必要 | Phase 4候補 |
| 独自Web設定画面 + NVS/LittleFS保存 | `pi_radio` の操作感に近づく | 実装量が増え、音声再生とのリソース競合が出る | Phase 4候補 |

推奨:

- 最初は固定SSIDで実験する。
- 秘密情報は `secrets.h` や `config.local.h` に分離し、`.gitignore` 対象にする。
- 実用化段階で SoftAP + Web設定、またはESP32-S3のUSB MSC TXT設定モードを入れる。
- USB MSC方式の詳細は `docs/usb_msc_config_plan.md` に分離する。

## Web設定画面を入れるべきか

最初からは入れない。

理由:

- まず確認すべきリスクは、ESP32-S3がHLS/AAC局を安定再生できるか、MAX98357Aでノイズなく音が出るか。
- Webサーバ、DNS、設定保存、HTML配信を同時に入れると、失敗時に原因が分かりにくい。
- `pi_radio` はLinux/NetworkManager/mpvの余裕があったが、ESP32ではメモリとタスク設計が制約になる。

入れるなら:

- 音声再生が安定した後。
- 設定項目は最小限:
  - Wi-Fi SSID/password
  - 局一覧URL
  - 音量初期値
  - 再起動ボタン
  - 現在のIP/再生状態/エラー表示
- 放送局URL編集を入れる場合は、長いURLやHLS URL変更に対応できるテキスト保存方式にする。

## 既存 pi_radio との違い

| 項目 | pi_radio | esp_radio案 |
|---|---|---|
| 本体 | Raspberry Pi 3B+ | ESP32-S3 PSRAM付き |
| 再生 | `mpv` + Linux ALSA | `ESP32-audioI2S` + I2S |
| 音声出力 | USB DAC -> PAM8403/外部アンプ | MAX98357A I2S DAC内蔵アンプ |
| OS | Linux | ベアメタル/Arduino/FreeRTOS |
| サービス化 | systemd | ファームウェア常時起動 |
| Wi-Fi | NetworkManager、既知Wi-Fi保存 | NVS/LittleFS/独自設定が必要 |
| UI | OLED + KY-040確認済み | OLED + KY-040を段階追加 |
| 安全停止 | 長押しで `shutdown -h now` | 原則不要。リセット/省電力/停止操作に置換 |
| 局再生の安定性 | mpvが強い | ライブラリ・PSRAM・HLS次第 |
| 保守 | SSHでログ確認しやすい | Serialログ/OTA/Webログ設計が必要 |
| 消費電力/サイズ | 大きめ | 小型・低消費電力化しやすい |

派生方針:

- `pi_radio` の局リスト、OLED表示項目、ロータリー操作思想を再利用する。
- Linux依存の systemd、NetworkManager、安全シャットダウンは移植しない。
- `esp_radio` では「小型・単機能・ファームウェア完結」を優先する。

## リスク

- PSRAMなしボードではライブラリ要件を満たさない可能性が高い。
- HLS/AAC局はPCやPiで再生できてもESP32で安定するとは限らない。
- 放送局URLは変更される可能性がある。特にNHKとABCは直接URLの寿命に注意。
- TLS証明書、HTTPSリダイレクト、SNI、User-Agent差で失敗する可能性がある。
- MAX98357AのGAIN/SD/MODE設定によって音量、左右ch、mono mix、ノイズが変わる。
- スピーカー電源電流が足りないとリセット、音割れ、ノイズが出る。
- OLEDとロータリーを追加すると、I2C/割り込み/描画更新が音声再生ループを邪魔する可能性がある。
- Web設定画面を入れるとメモリとタスク競合が増える。

## 最小実験手順

まだ実装しないが、次回作業の入口として以下を想定する。

1. 使用するESP32-S3ボード型番を確認する。
2. PSRAM有無、Flash容量、使用不可ピンを確認する。
3. MAX98357Aを `BCLK` / `LRC` / `DIN` / `VIN` / `GND` だけで接続する。
4. PlatformIO または Arduino IDE で `ESP32-audioI2S` の最小スケッチを作る。
5. `ESP.getPsramSize()`、Wi-Fi接続、IPアドレスをSerialに出す。
6. WNYC `https://fm939.wnyc.org/wnycfm` だけを再生する。
7. 音が出たら、音量初期値を低めから上げる。
8. BBC/NHK/ABCのHLS URLを1つずつ試す。
9. 成功/失敗時のSerialログ、codec名、最後に接続したURLを記録する。
10. その後にOLED、ロータリー、Wi-Fi設定、Web設定画面の順で足す。

## 採用候補構成

初期:

- ESP32-S3 PSRAM付き開発ボード。
- MAX98357A I2S Class-D mono amp。
- 2インチ級 / 53mm / 4Ω / 3W フルレンジスピーカー。
- 5V USB電源。
- `ESP32-audioI2S`。
- 固定SSID + WNYC固定URL。

次段階:

- SSD1306/SH1106 128x64 I2C OLED。
- GM009606v4.3 OLED。`SSD1306 128x64 / I2C 0x3C` として開始。
- KY-040ロータリーエンコーダ。
- 複数局テーブル。
- NVS/LittleFS設定保存。
- SoftAP設定モード。

後回し:

- Web設定画面。
- USB MSC TXT設定モード。
- OTA。
- MQTT。
- SDカード局リスト。
- 起動音/効果音。

## 参考リンク

- `schreibfaul1/ESP32-audioI2S`: https://github.com/schreibfaul1/ESP32-audioI2S
- `ESP32-audioI2S` Wiki: https://github.com/schreibfaul1/ESP32-audioI2S/wiki
- `Edzelf/ESP32Radio-V2`: https://github.com/Edzelf/ESP32Radio-V2
- `Edzelf/ESP32-Radio`: https://github.com/Edzelf/ESP32-Radio
- Adafruit MAX98357A pinouts: https://learn.adafruit.com/adafruit-max98357-i2s-class-d-mono-amp/pinouts
- Espressif Arduino I2S API: https://docs.espressif.com/projects/arduino-esp32/en/latest/api/i2s.html
- `pi_radio` local reference: `D:\data\codex\pi_radio`

## 完了条件

- `docs/esp32_i2s_radio_research.md` に、前例、PSRAM要否、I2S配線、対応形式、局URL見込み、OLED/ロータリー構成、Wi-Fi設定、Web設定画面の要否、`pi_radio`との差分、リスク、最小実験手順が整理されている。
- 実装コードやPlatformIOプロジェクトはまだ作成しない。

## 作業後チェック

- 実装開始を示すファイルが増えていない。
- 秘密情報、Wi-Fiパスワード、APIキーが含まれていない。
- 局URLの確認結果が `PC上のffprobe確認` と `ESP32実機再生確認` で混ざっていない。
- `pi_radio` で確認済みの事実と、`esp_radio` の未確認仮説が区別されている。

## 失敗条件

- PSRAMなしESP32-S3でも確実に動くと断定している。
- HLS/AAC局を実機未確認なのに再生可能と断定している。
- Web設定画面を最小実験の必須要件にしている。
- `pi_radio` のLinux/systemd/NetworkManager前提をESP32へそのまま移植する前提になっている。

## 報告してほしい内容

- どの前例を第一候補にしたか。
- PSRAM付きESP32-S3を推奨する理由。
- 最初に試す局URL。
- 実装前に残っている主なリスク。
- 次回実装に入る場合の最初の作業入口。

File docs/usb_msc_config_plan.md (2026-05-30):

# USB MSC TXT Configuration Plan

作成日: 2026-05-30

## 目的

`esp32_radio` を友人へ渡したあと、PCとUSBケーブルで接続して `WIFI.TXT` や `STATIONS.TXT` を書き換えられる構成を将来候補にする。

初期実験ではWi-Fi SSID/passwordをコードまたはローカル専用設定ファイルに書く。再生確認ができた後、ESP32-S3のネイティブUSB Device機能を使い、設定モード時だけ小さなUSB Mass StorageとしてPCに見せる方式を検討する。

## 結論

- ESP32-S3 N16R8なら実験候補として現実的。
- ESP32-WROOM-32Eでは基本的に不可。USB端子はUSB-シリアル変換チップ経由で、PCからはCOMポートに見えるだけ。
- 最初から実装せず、音声再生、OLED表示、ロータリー操作が安定してから後段で試す。
- 安全のため、PCにUSBドライブとして見せるのは専用の設定モード中だけにする。

## 想定UX

```text
1. 電源OFF
2. 設定ボタンを押しながらUSB接続、またはロータリー長押しで設定モード起動
3. PCに `ESP_RADIO` のような小さいUSBドライブが表示される
4. `WIFI.TXT` と `STATIONS.TXT` を編集する
5. PC側で取り外し操作をする
6. ESP32-S3を再起動する
7. 起動時にTXTを読み、NVS/LittleFS側の運用設定へ反映する
```

## 設定ファイル案

### WIFI.TXT

```text
ssid=YOUR_WIFI_NAME
password: YOUR_WIFI_PASSWORD
hostname=esp-radio
```

注意:

- `WIFI.TXT` はローカル設定用で、GitHubへ入れない。
- 配布用repoには `WIFI.EXAMPLE.TXT` だけ置く。
- 実機上の設定ファイルは秘密情報なので、ログやOLEDにpasswordを出さない。

### STATIONS.TXT

```text
WNYC FM|https://fm939.wnyc.org/wnycfm
BBC Radio 4|https://example.invalid/bbc-radio-4.m3u8
NHK R1|https://example.invalid/nhk-r1.m3u8
```

注意:

- 実際の放送局URLは変わる可能性がある。
- HLS/AAC局はESP32実機で再生できるか確認してから配布候補にする。
- 1行1局、`局名|URL` の単純形式にすると、人間が編集しやすい。

## 実装方針

### Phase 1: 通常設定

- `include/config.local.h` など、git除外ファイルにWi-Fi情報を書く。
- WNYC固定URLで再生確認する。

### Phase 2: 内部保存

- NVSまたはLittleFSに設定を保存する。
- 起動時に設定がなければデフォルト局だけで起動する。

### Phase 3: USB MSC設定モード

- ESP32-S3のTinyUSB / USB MSC機能を調査する。
- FATの小さな設定領域をPCへ見せる。
- PCがマウントしている間は、ESP32側はその領域を同時に読み書きしない。
- 設定モードを抜けたあと、TXTを検証してNVS/LittleFSへ反映する。

## 競合・破損対策

USB Mass Storageは、PCがブロックデバイスとしてファイルシステムを触る。ESP32側も同時に同じ領域を読み書きすると破損リスクがある。

安全策:

- 設定モード中はラジオ再生しない。
- 設定モード中はESP32側から設定領域へ書かない。
- PC側の取り外し後、または再起動後に設定を読む。
- 読み込む前にTXT形式を検証する。
- 不正な設定なら前回の有効設定を維持する。

## OLED表示

設定モード時は、`pi_radio` と同じOLEDに状態を出す。

想定表示:

```text
USB CONFIG
EDIT TXT FILES
EJECT + RESET
```

通常起動時:

```text
ESP RADIO
WIFI...
```

設定読み込み失敗時:

```text
CONFIG ERROR
WIFI.TXT
```

## 参考

- ESP-IDF USB Device Stack / TinyUSB: https://docs.espressif.com/projects/esp-idf/en/stable/esp32s3/api-reference/peripherals/usb_device.html
- Espressif USB FAQ / USB MSC: https://documentation.espressif.com/projects/esp-faq/en/latest/software-framework/peripherals/usb.html

## 完了条件

- 初期実験では実装しない将来候補として明確に分離されている。
- WROOM-32EではなくESP32-S3 N16R8向けの案として書かれている。
- PC接続中の同時書き込みリスクと、設定モード限定の方針が明記されている。
- `WIFI.TXT` などの秘密情報をGitHubへ入れない方針が明記されている。

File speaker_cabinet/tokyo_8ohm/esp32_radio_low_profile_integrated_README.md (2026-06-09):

# ESP32 Radio Low Profile Integrated Cabinet

This draft combines the speaker cabinet and the ESP32 radio front controls into one compact enclosure.

## Layout

- Bottom: F12E28A01-1 / 30 x 70 mm oval speaker, rotated horizontally.
- Upper center: bass-reflex style port.
- Top left: 12 x 4 mm slot for the external OLED board pin header.
- Upper right: KY-040 / volume knob shaft only. The extra KY-040 mounting holes and rear landing frame are omitted.
- Inside: open space for the ESP32-S3 board and MAX98357A board. No front-side board pads are modeled.

## Dimensions

| Item | Value |
|---|---:|
| Outer size | 118 x 70 x 52 mm |
| Wall | 4.0 mm |
| Front baffle | 4.0 mm |
| Speaker opening | 66 x 26 mm rounded slot |
| OLED/header opening | 12 x 4 mm rounded slot |
| Port | 9.5 mm x 22 mm tube |
| Rear cover lip | 1.0 mm deep, 1.2 mm clearance per side |
| Front-shell screw receivers | 5.0 mm deep rectangular corner blocks |

## Files

- `esp32_radio_low_profile_integrated.scad`: OpenSCAD source.
- `esp32_radio_low_profile_front_shell.stl`: printable front shell.
- `esp32_radio_low_profile_back_cover.stl`: printable rear cover.
- `esp32_radio_low_profile_port_plug.stl`: optional port plug.
- `esp32_radio_low_profile_front_layout.png`: front layout diagram showing display, port, volume knob, and speaker positions.

## Notes

- This is intentionally shallow, but deeper than the first round-speaker draft because the F12E28A01-1 drawing shows about 39.5 mm speaker depth.
- Check speaker terminal clearance and USB plug clearance before final printing.
- Use foam tape or a thin gasket around the speaker rim.
- If the port makes voices muddy, insert the port plug.
- Speaker screw holes are disabled until the actual tab hole positions are measured on the real unit.
- The speaker opening is a plain 66 x 26 mm rounded through-slot; the previous inner alignment groove was removed.
- The KY-040 has only the center shaft hole; rear pockets and extra service openings were removed.
- The four rear-cover screw receivers are compact rectangular blocks near the rear opening, with about 3 mm of material around each screw hole.
- The OLED board is assumed to sit outside the cabinet; only its pin header enters through the 12 x 4 mm slot.
- The top/service cutouts were intentionally removed; add cable exits later only after the real board placement is fixed.
- The rear cover lip was reduced from the first PETG print: the former 0.35 mm per-side clearance was too tight for the printed front shell.

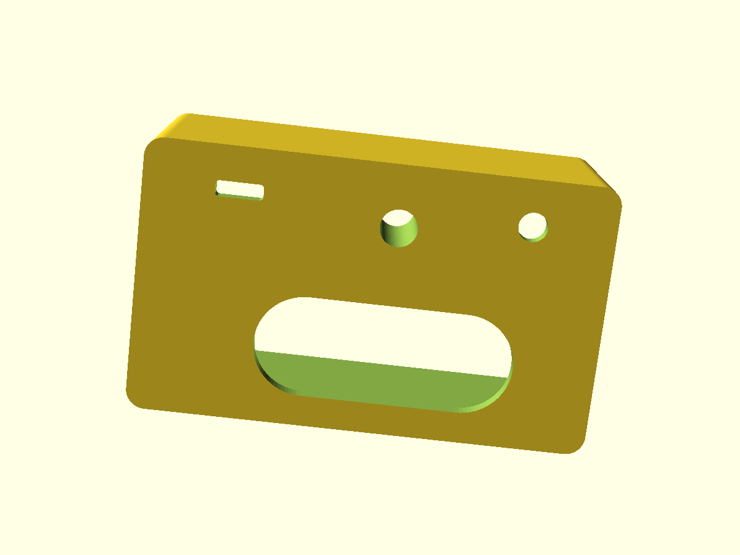
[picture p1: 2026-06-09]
speaker_cabinet/tokyo_8ohm/esp32_radio_low_profile_front_angle_preview.png

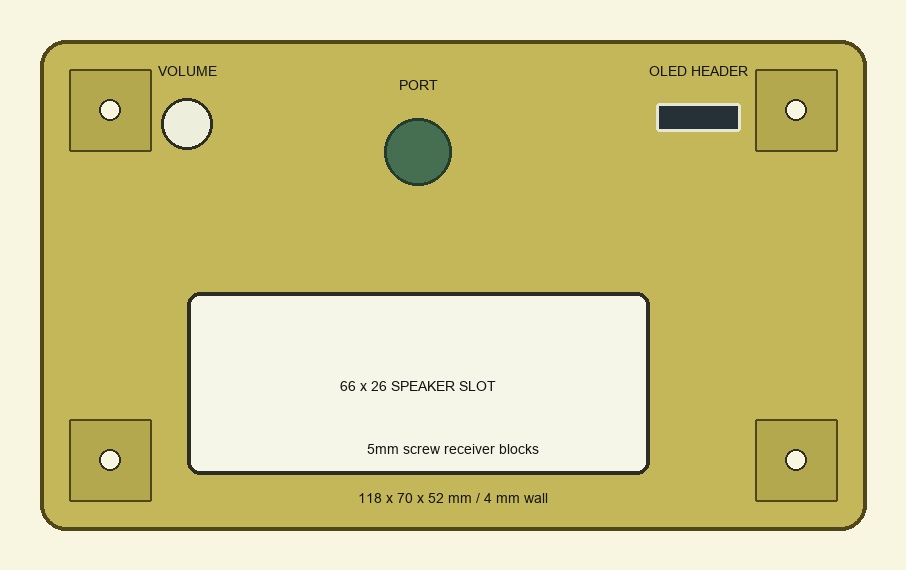
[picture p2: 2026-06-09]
speaker_cabinet/tokyo_8ohm/esp32_radio_low_profile_front_layout.png

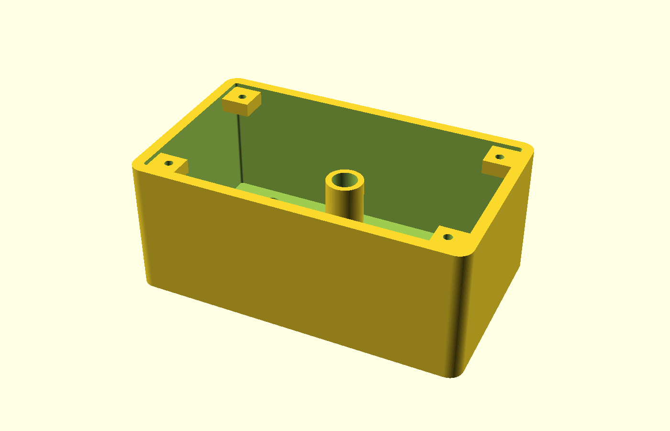
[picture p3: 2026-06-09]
speaker_cabinet/tokyo_8ohm/esp32_radio_low_profile_preview.png

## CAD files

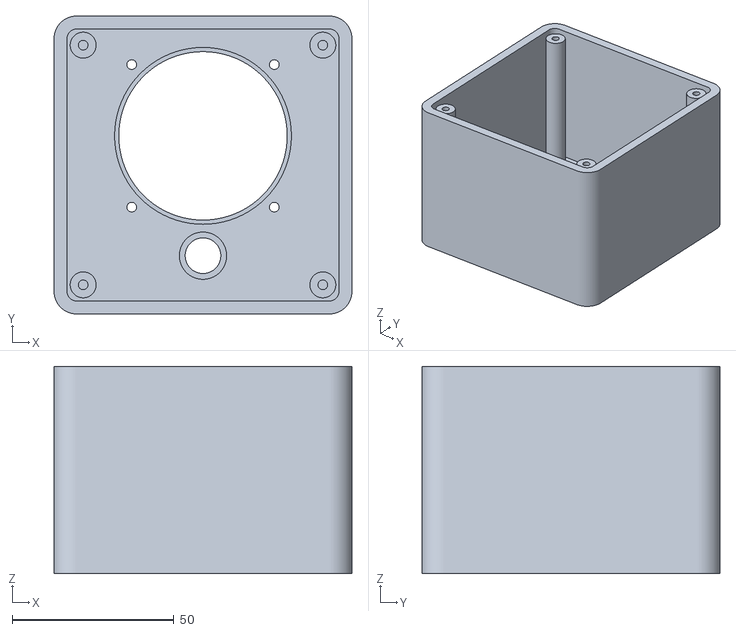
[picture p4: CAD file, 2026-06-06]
speaker_cabinet/daiso_4ohm/toilet_bgm_speaker_tuned_front_cabinet.stl
92.0 x 92.0 x 64.0

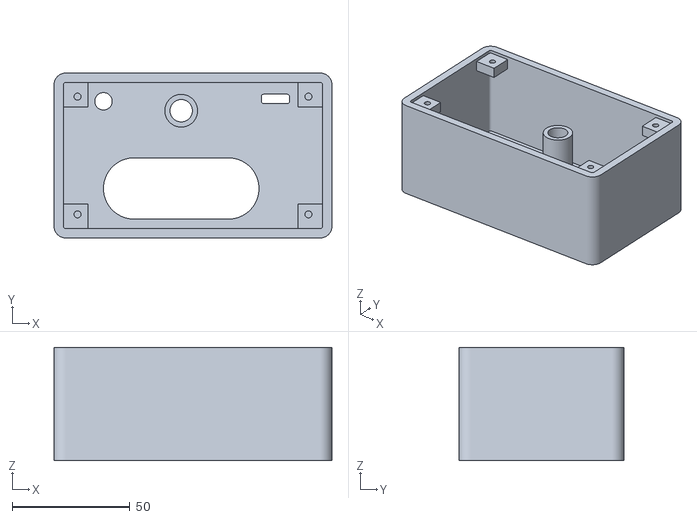
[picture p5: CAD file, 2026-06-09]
speaker_cabinet/tokyo_8ohm/esp32_radio_low_profile_front_shell.stl
118.0 x 70.0 x 48.0

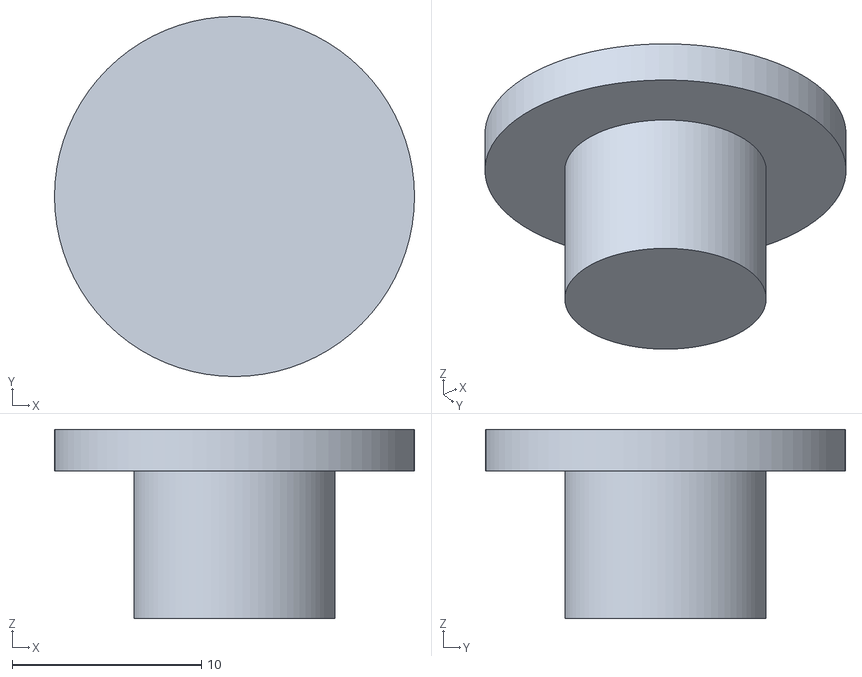
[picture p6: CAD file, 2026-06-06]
speaker_cabinet/daiso_4ohm/toilet_bgm_speaker_tuned_port_plug.stl
19.0 x 19.0 x 10.0

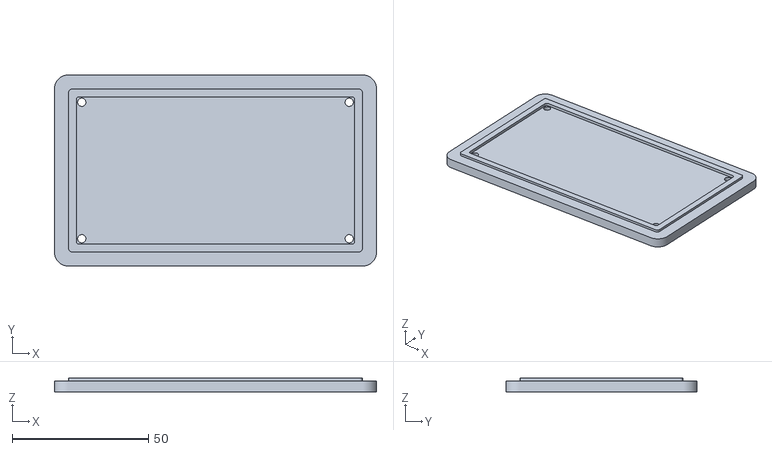
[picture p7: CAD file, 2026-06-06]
speaker_cabinet/tokyo_8ohm/esp32_radio_low_profile_back_cover.stl
118.0 x 70.0 x 5.00

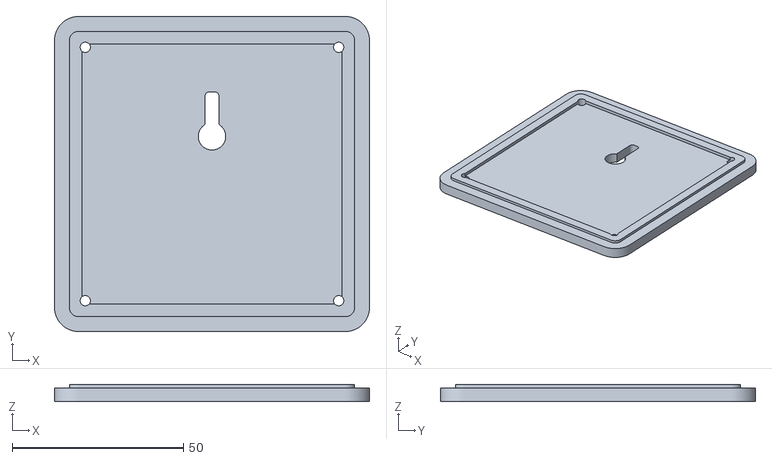
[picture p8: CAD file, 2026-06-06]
speaker_cabinet/daiso_4ohm/toilet_bgm_speaker_tuned_rear_cover.stl
92.0 x 92.0 x 5.00

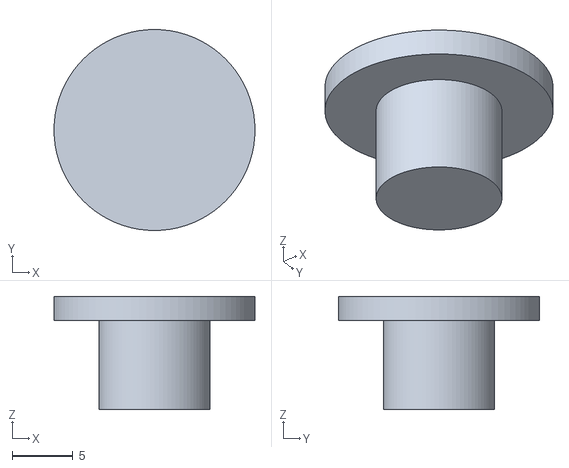
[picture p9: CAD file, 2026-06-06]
speaker_cabinet/tokyo_8ohm/esp32_radio_low_profile_port_plug.stl
16.5 x 16.5 x 9.30

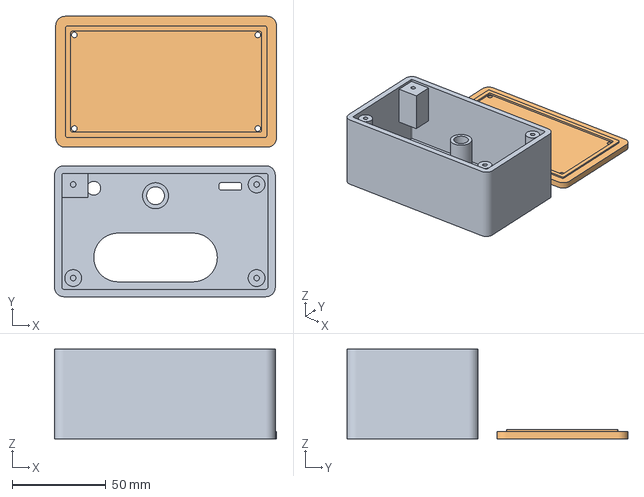
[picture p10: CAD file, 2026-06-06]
speaker_cabinet/tokyo_8ohm/TOKYO系esp32_radio_low_profile_front_shell.3mf
118.6 x 149.9 x 48.0 mm
esp32_radio_low_profile_front_shell.stl
esp32_radio_low_profile_back_cover.stl

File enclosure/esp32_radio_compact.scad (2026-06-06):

/*
  ESP32 radio compact enclosure

  Layout on the front face, left to right:
  KY-040 knob, 53 mm speaker, SSD1306 128x64 OLED.

  All dimensions are millimeters. Measure the arrived parts and tune the
  parameter block before printing the final version.
*/

$fn = 64;

// 0 = assembly, 1 = front_shell, 2 = back_cover
part_mode = 0;

// Case
case_w = 145;
case_h = 78;
case_d = 48;
wall = 2.4;
corner_r = 5;
front_th = 3.0;
back_th = 2.4;
lip_depth = 5;
lip_clearance = 0.35;

// Layout
knob_x = 23;
speaker_x = 65;
display_x = 113;
ui_y = 39;

// KY-040 / knob
encoder_shaft_hole_d = 7.4;
encoder_mount_hole_d = 3.2;
encoder_mount_spacing = 27;
encoder_body_clearance_w = 31;
encoder_body_clearance_h = 34;
encoder_body_clearance_d = 15;

// Speaker, from current project notes: outer diameter about 52.6-53 mm,
// depth about 30 mm.
speaker_outer_d = 53.4;
speaker_cutout_d = 47;
speaker_depth_clearance = 32;
speaker_screw_circle_d = 45;
speaker_screw_hole_d = 3.0;
speaker_screw_count = 4;
speaker_mount_holes_enabled = false;
speaker_grille_enabled = false;
grille_hole_d = 3.0;
grille_ring_step = 6.2;
grille_max_r = 19;

// OLED module. Defaults fit common 0.96 inch SSD1306 boards; adjust to GM009606.
oled_window_w = 26;
oled_window_h = 15;
oled_board_w = 28;
oled_board_h = 28;
oled_board_clearance_d = 8;
oled_screw_spacing_x = 23;
oled_screw_spacing_y = 23;
oled_screw_hole_d = 2.2;

// Rear cover and fasteners
cover_screw_d = 3.0;
cover_boss_outer_d = 7.2;
cover_screw_offset = 8;
usb_cutout_w = 14;
usb_cutout_h = 8;

module rounded_rect_2d(w, h, r) {
  hull() {
    translate([-(w / 2 - r), -(h / 2 - r)]) circle(r = r);
    translate([ (w / 2 - r), -(h / 2 - r)]) circle(r = r);
    translate([-(w / 2 - r),  (h / 2 - r)]) circle(r = r);
    translate([ (w / 2 - r),  (h / 2 - r)]) circle(r = r);
  }
}

module rounded_box(w, h, d, r) {
  linear_extrude(height = d)
    rounded_rect_2d(w, h, r);
}

module case_box(w, h, d, r) {
  translate([w / 2, h / 2, 0])
    rounded_box(w, h, d, r);
}

module front_panel_shape() {
  case_box(case_w, case_h, front_th, corner_r);
}

module grille_holes() {
  for (x = [-grille_max_r : grille_ring_step : grille_max_r]) {
    for (y = [-grille_max_r : grille_ring_step : grille_max_r]) {
      r = sqrt(x * x + y * y);
      if (r <= grille_max_r && r > 5) {
        translate([speaker_x + x, ui_y + y, -0.2])
          cylinder(h = front_th + 0.4, d = grille_hole_d);
      }
    }
  }
}

module speaker_mount_holes() {
  for (i = [0 : speaker_screw_count - 1]) {
    a = 360 / speaker_screw_count * i + 45;
    translate([
      speaker_x + cos(a) * speaker_screw_circle_d / 2,
      ui_y + sin(a) * speaker_screw_circle_d / 2,
      -0.2
    ])
      cylinder(h = front_th + 0.4, d = speaker_screw_hole_d);
  }
}

module front_cutouts() {
  // Knob shaft and optional KY-040 board mounting holes.
  translate([knob_x, ui_y, -0.2])
    cylinder(h = front_th + 0.4, d = encoder_shaft_hole_d);
  for (dy = [-encoder_mount_spacing / 2, encoder_mount_spacing / 2]) {
    translate([knob_x, ui_y + dy, -0.2])
      cylinder(h = front_th + 0.4, d = encoder_mount_hole_d);
  }

  // Speaker acoustic opening and grille.
  if (speaker_cutout_d > 0) {
    translate([speaker_x, ui_y, -0.2])
      cylinder(h = front_th + 0.4, d = speaker_cutout_d);
  }
  if (speaker_grille_enabled) {
    grille_holes();
  }
  if (speaker_mount_holes_enabled) {
    speaker_mount_holes();
  }

  // OLED viewing window.
  translate([display_x, ui_y, -0.2])
    linear_extrude(height = front_th + 0.4)
      rounded_rect_2d(oled_window_w, oled_window_h, 1.2);
}

module front_shell_wall() {
  difference() {
    case_box(case_w, case_h, case_d - back_th, corner_r);
    translate([wall, wall, front_th])
      case_box(case_w - wall * 2, case_h - wall * 2, case_d, max(corner_r - wall, 1));
    // Rear opening.
    translate([wall, wall, case_d - back_th - 0.2])
      case_box(case_w - wall * 2, case_h - wall * 2, back_th + 0.4, max(corner_r - wall, 1));
    // USB/service cutout on the bottom rear.
    translate([case_w / 2, case_h / 2, case_d - 20])
      rotate([90, 0, 0])
        linear_extrude(height = wall + 0.6)
          rounded_rect_2d(usb_cutout_w, usb_cutout_h, 1.2);
  }
}

module standoff(x, y, z, h, od, id) {
  translate([x, y, z])
    difference() {
      cylinder(h = h, d = od);
      translate([0, 0, -0.2])
        cylinder(h = h + 0.4, d = id);
    }
}

module internal_mounts() {
  // Speaker support ring.
  translate([speaker_x, ui_y, front_th])
    difference() {
      cylinder(h = 4, d = speaker_outer_d + 4);
      translate([0, 0, -0.2])
        cylinder(h = 4.4, d = speaker_outer_d + 0.6);
    }

  // OLED board standoffs.
  for (sx = [-1, 1]) {
    for (sy = [-1, 1]) {
      standoff(
        display_x + sx * oled_screw_spacing_x / 2,
        ui_y + sy * oled_screw_spacing_y / 2,
        front_th,
        oled_board_clearance_d,
        5.2,
        oled_screw_hole_d
      );
    }
  }

  // Encoder board clearance frame, useful as a glue/screw landing zone.
  translate([knob_x, ui_y, front_th])
    difference() {
      linear_extrude(height = 3)
        rounded_rect_2d(encoder_body_clearance_w + 4, encoder_body_clearance_h + 4, 2);
      translate([0, 0, -0.2])
        linear_extrude(height = 3.4)
          rounded_rect_2d(encoder_body_clearance_w, encoder_body_clearance_h, 1.5);
    }

  // Rear cover bosses.
  for (x = [cover_screw_offset, case_w - cover_screw_offset]) {
    for (y = [cover_screw_offset, case_h - cover_screw_offset]) {
      standoff(x, y, front_th, case_d - front_th - back_th - 1.5, cover_boss_outer_d, cover_screw_d);
    }
  }
}

module front_shell() {
  difference() {
    union() {
      front_shell_wall();
      internal_mounts();
    }
    front_cutouts();
    // Speaker rear clearance.
    translate([speaker_x, ui_y, front_th + 1])
      cylinder(h = speaker_depth_clearance, d = speaker_outer_d + 1.0);
    // OLED board rear clearance.
    translate([display_x, ui_y, front_th + 1])
      linear_extrude(height = oled_board_clearance_d + 1)
        rounded_rect_2d(oled_board_w + 1.0, oled_board_h + 1.0, 1.5);
    // Encoder body rear clearance.
    translate([knob_x, ui_y, front_th + 1])
      linear_extrude(height = encoder_body_clearance_d + 1)
        rounded_rect_2d(encoder_body_clearance_w, encoder_body_clearance_h, 1.5);
  }
}

module back_cover() {
  difference() {
    union() {
      case_box(case_w, case_h, back_th, corner_r);
      translate([wall + lip_clearance, wall + lip_clearance, back_th])
        case_box(
          case_w - wall * 2 - lip_clearance * 2,
          case_h - wall * 2 - lip_clearance * 2,
          lip_depth,
          max(corner_r - wall - lip_clearance, 1)
        );
    }
    translate([wall * 2, wall * 2, back_th - 0.2])
      case_box(
        case_w - wall * 4,
        case_h - wall * 4,
        lip_depth + 0.4,
        max(corner_r - wall * 2, 1)
      );
    for (x = [cover_screw_offset, case_w - cover_screw_offset]) {
      for (y = [cover_screw_offset, case_h - cover_screw_offset]) {
        translate([x, y, -0.2])
          cylinder(h = back_th + lip_depth + 0.4, d = cover_screw_d);
      }
    }
  }
}

if (part_mode == 1) {
  front_shell();
} else if (part_mode == 2) {
  back_cover();
} else {
  front_shell();
  translate([0, case_h + 10, 0]) back_cover();
}

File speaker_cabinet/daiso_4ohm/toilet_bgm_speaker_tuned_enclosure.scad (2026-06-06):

/*
  Larger BGM-oriented enclosure for the low-cost 53 mm / 4 ohm speaker.

  This is not a mathematically tuned hi-fi cabinet. The speaker's Thiele/Small
  parameters are unknown, so the design focuses on practical improvements:
  - larger rear air volume than the minimal box
  - stiffer front baffle
  - shallow speaker recess for a foam gasket
  - front-facing port that can be plugged if the result sounds boomy

  Print parts:
  - part_mode = 1: front cabinet
  - part_mode = 2: rear cover
  - part_mode = 3: port plug
  - part_mode = 0: all parts side by side

  All dimensions are millimeters.
*/

$fn = 80;

part_mode = 0;

// A larger cabinet for better speech/BGM fullness.
box_w = 92;
box_h = 92;
box_d = 68;
wall = 4.0;
corner_r = 7;
front_th = 4.0;
back_th = 4.0;

// Speaker.
speaker_outer_d = 53.4;
speaker_recess_d = 54.6;
speaker_recess_depth = 2.0;
speaker_cutout_d = 52.0;
speaker_body_clearance_d = 56.0;
speaker_depth_clearance = 33.0;
speaker_x = box_w / 2;
speaker_y = 55;

speaker_mount_holes_enabled = true;
speaker_screw_spacing = 44.0; // 44 mm square, about 62.2 mm diagonal.
speaker_screw_hole_d = 3.0;

// Front bass-reflex style port. Treat it as an adjustable experiment.
port_enabled = true;
port_d = 11.0;
port_len = 34.0;
port_x = box_w / 2;
port_y = 18;
port_wall = 1.8;

// Rear cover and screws.
lip_depth = 1.0;
lip_clearance = 0.35;
cover_screw_d = 3.0;
cover_boss_d = 8.0;
cover_screw_offset = 9.0;

// Rear cable exit. Face this downward if wall-mounted.
wire_slot_w = 9.0;
wire_slot_h = 4.5;

// Optional wall/keyhole slots in the rear cover.
keyhole_enabled = true;
keyhole_big_d = 8.0;
keyhole_slot_w = 4.0;
keyhole_slot_h = 13.0;

module rounded_rect_2d(w, h, r) {
  hull() {
    translate([-(w / 2 - r), -(h / 2 - r)]) circle(r = r);
    translate([ (w / 2 - r), -(h / 2 - r)]) circle(r = r);
    translate([-(w / 2 - r),  (h / 2 - r)]) circle(r = r);
    translate([ (w / 2 - r),  (h / 2 - r)]) circle(r = r);
  }
}

module rounded_box(w, h, d, r) {
  linear_extrude(height = d)
    rounded_rect_2d(w, h, r);
}

module case_box(w, h, d, r) {
  translate([w / 2, h / 2, 0])
    rounded_box(w, h, d, r);
}

module standoff(x, y, z, h, od, id) {
  translate([x, y, z])
    difference() {
      cylinder(h = h, d = od);
      translate([0, 0, -0.2])
        cylinder(h = h + 0.4, d = id);
    }
}

module speaker_mount_holes() {
  for (sx = [-1, 1]) {
    for (sy = [-1, 1]) {
      translate([
        speaker_x + sx * speaker_screw_spacing / 2,
        speaker_y + sy * speaker_screw_spacing / 2,
        -0.2
      ])
        cylinder(h = front_th + 0.4, d = speaker_screw_hole_d);
    }
  }
}

module front_openings() {
  translate([speaker_x, speaker_y, -0.2])
    cylinder(h = front_th + 0.4, d = speaker_cutout_d);

  translate([speaker_x, speaker_y, front_th - speaker_recess_depth])
    cylinder(h = speaker_recess_depth + 0.4, d = speaker_recess_d);

  if (speaker_mount_holes_enabled) {
    speaker_mount_holes();
  }

  if (port_enabled) {
    translate([port_x, port_y, -0.2])
      cylinder(h = front_th + 0.4, d = port_d);
  }
}

module rear_wire_slot() {
  translate([box_w / 2, -0.3, box_d - back_th - wire_slot_h / 2])
    rotate([90, 0, 0])
      linear_extrude(height = wall + 0.6)
        rounded_rect_2d(wire_slot_w, wire_slot_h, 1.2);
}

module cabinet_wall() {
  difference() {
    case_box(box_w, box_h, box_d - back_th, corner_r);

    translate([wall, wall, front_th])
      case_box(
        box_w - wall * 2,
        box_h - wall * 2,
        box_d,
        max(corner_r - wall, 1)
      );

    translate([wall, wall, box_d - back_th - 0.2])
      case_box(
        box_w - wall * 2,
        box_h - wall * 2,
        back_th + 0.4,
        max(corner_r - wall, 1)
      );

    rear_wire_slot();
  }
}

module port_tube() {
  if (port_enabled) {
    translate([port_x, port_y, front_th - 0.2])
      difference() {
        cylinder(h = port_len + 0.2, d = port_d + port_wall * 2);
        translate([0, 0, -0.2])
          cylinder(h = port_len + 0.6, d = port_d);
      }
  }
}

module internal_features() {
  port_tube();

  for (x = [cover_screw_offset, box_w - cover_screw_offset]) {
    for (y = [cover_screw_offset, box_h - cover_screw_offset]) {
      standoff(x, y, front_th, box_d - front_th - back_th - 1.5, cover_boss_d, cover_screw_d);
    }
  }
}

module front_cabinet() {
  difference() {
    union() {
      cabinet_wall();
      internal_features();
    }

    front_openings();

    translate([speaker_x, speaker_y, front_th + 1])
      cylinder(h = speaker_depth_clearance, d = speaker_body_clearance_d);
  }
}

module keyhole_cutout(x, y) {
  translate([x, y, -0.2])
    cylinder(h = back_th + lip_depth + 0.4, d = keyhole_big_d);

  translate([x, y + keyhole_slot_h / 2, -0.2])
    linear_extrude(height = back_th + lip_depth + 0.4)
      rounded_rect_2d(keyhole_slot_w, keyhole_slot_h, 1.2);
}

module rear_cover() {
  difference() {
    union() {
      case_box(box_w, box_h, back_th, corner_r);

      translate([wall + lip_clearance, wall + lip_clearance, back_th - 0.15])
        case_box(
          box_w - wall * 2 - lip_clearance * 2,
          box_h - wall * 2 - lip_clearance * 2,
          lip_depth + 0.15,
          max(corner_r - wall - lip_clearance, 1)
        );
    }

    translate([wall * 2, wall * 2, back_th - 0.2])
      case_box(
        box_w - wall * 4,
        box_h - wall * 4,
        lip_depth + 0.4,
        max(corner_r - wall * 2, 1)
      );

    for (x = [cover_screw_offset, box_w - cover_screw_offset]) {
      for (y = [cover_screw_offset, box_h - cover_screw_offset]) {
        translate([x, y, -0.2])
          cylinder(h = back_th + lip_depth + 0.4, d = cover_screw_d);
      }
    }

    if (keyhole_enabled) {
      keyhole_cutout(box_w / 2, box_h / 2 + 11);
    }
  }
}

module port_plug() {
  plug_len = 8;
  grip_d = port_d + 8;

  union() {
    cylinder(h = plug_len, d = port_d - 0.4);
    translate([0, 0, plug_len - 0.2])
      cylinder(h = 2.2, d = grip_d);
  }
}

if (part_mode == 1) {
  front_cabinet();
} else if (part_mode == 2) {
  rear_cover();
} else if (part_mode == 3) {
  port_plug();
} else {
  front_cabinet();
  translate([box_w + 12, 0, 0]) rear_cover();
  translate([box_w * 2 + 28, 24, 0]) port_plug();
}

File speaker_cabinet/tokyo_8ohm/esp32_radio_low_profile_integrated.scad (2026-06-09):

/*
  ESP32 radio low-profile integrated cabinet

  Front layout:
  - F12E28A01-1 oval speaker at the bottom
  - bass-reflex style port above the speaker
  - OLED display left of the port
  - volume knob right of the port

  This is a compact packaging draft for the radio electronics, not a final
  measured production model. Measure the actual speaker, OLED, encoder, ESP32
  board, and wire bends before printing the final version.

  Print parts:
  - part_mode = 1: front shell
  - part_mode = 2: rear cover
  - part_mode = 3: port plug
  - part_mode = 0: all parts side by side

  All dimensions are millimeters.
*/

$fn = 80;

part_mode = 0;

// Low profile cabinet. Depth is limited by the F12E28A01-1 depth of about
// 39.5 mm plus front baffle, rear cover, and wire clearance.
case_w = 118;
case_h = 70;
case_d = 52;
wall = 4.0;
corner_r = 5;
front_th = 4.0;
back_th = 4.0;

// Front layout.
speaker_x = 54;
speaker_y = 21;
port_x = 54;
port_y = 54;
display_x = 94;
display_y = 59;
knob_x = 21;
knob_y = 58;

// F12E28A01-1 is a 30 x 70 mm oval speaker. The front opening is kept to the
// measured 66 x 26 mm rounded slot only; no inner alignment groove is modeled.
speaker_cutout_w = 66.0;
speaker_cutout_h = 26.0;
speaker_cutout_r = 13.0;

speaker_mount_holes_enabled = false;
speaker_screw_span_x = 81.0;
speaker_screw_span_y = 35.0;
speaker_screw_hole_d = 3.6;

// Port. Keep short because the cabinet is shallow; use the plug if muddy.
port_enabled = true;
port_d = 9.5;
port_len = 22;
port_wall = 2.2;

// OLED board stays outside; only its pin header enters the cabinet.
oled_header_slot_w = 12;
oled_header_slot_h = 4;

// KY-040 / volume knob. Only the center shaft hole is cut on the front panel.
encoder_shaft_hole_d = 7.4;
// Rear cover.
lip_depth = 1.0;
lip_clearance = 1.2;
cover_screw_d = 3.0;
cover_screw_offset = 10.0;
cover_receiver_depth = 5.0;
cover_receiver_wall = 3.0;
cover_receiver_overlap = 1.2;

module rounded_rect_2d(w, h, r) {
  hull() {
    translate([-(w / 2 - r), -(h / 2 - r)]) circle(r = r);
    translate([ (w / 2 - r), -(h / 2 - r)]) circle(r = r);
    translate([-(w / 2 - r),  (h / 2 - r)]) circle(r = r);
    translate([ (w / 2 - r),  (h / 2 - r)]) circle(r = r);
  }
}

module rounded_box(w, h, d, r) {
  linear_extrude(height = d)
    rounded_rect_2d(w, h, r);
}

module case_box(w, h, d, r) {
  translate([w / 2, h / 2, 0])
    rounded_box(w, h, d, r);
}

module speaker_mount_holes() {
  // Optional rectangular mounting pattern for the oval speaker tabs.
  for (sx = [-1, 1]) {
    for (sy = [-1, 1]) {
      translate([
        speaker_x + sx * speaker_screw_span_x / 2,
        speaker_y + sy * speaker_screw_span_y / 2,
        -0.2
      ])
        cylinder(h = front_th + 0.4, d = speaker_screw_hole_d);
    }
  }
}

module front_cutouts() {
  translate([speaker_x, speaker_y, -0.2])
    linear_extrude(height = front_th + 0.4)
      rounded_rect_2d(speaker_cutout_w, speaker_cutout_h, speaker_cutout_r);

  if (speaker_mount_holes_enabled) {
    speaker_mount_holes();
  }

  if (port_enabled) {
    translate([port_x, port_y, -0.2])
      cylinder(h = front_th + 0.4, d = port_d);
  }

  translate([display_x, display_y, -0.2])
    linear_extrude(height = front_th + 0.4)
      rounded_rect_2d(oled_header_slot_w, oled_header_slot_h, 1.0);

  translate([knob_x, knob_y, -0.2])
    cylinder(h = front_th + 0.4, d = encoder_shaft_hole_d);
}

module front_shell_wall() {
  difference() {
    case_box(case_w, case_h, case_d - back_th, corner_r);

    translate([wall, wall, front_th])
      case_box(
        case_w - wall * 2,
        case_h - wall * 2,
        case_d,
        max(corner_r - wall, 1)
      );

    translate([wall, wall, case_d - back_th - 0.2])
      case_box(
        case_w - wall * 2,
        case_h - wall * 2,
        back_th + 0.4,
        max(corner_r - wall, 1)
      );

  }
}

module port_tube() {
  if (port_enabled) {
    translate([port_x, port_y, front_th - 0.2])
      difference() {
        cylinder(h = port_len + 0.2, d = port_d + port_wall * 2);
        translate([0, 0, -0.2])
          cylinder(h = port_len + 0.6, d = port_d);
      }
  }
}

module cover_screw_receiver(x, y) {
  // Compact rectangular screw receiver near the rear opening. The receiver is
  // tied into its two adjacent walls, while the screw hole center stays fixed.
  hole_r = cover_screw_d / 2;
  half = hole_r + cover_receiver_wall;
  left_side = x < case_w / 2;
  bottom_side = y < case_h / 2;
  block_left = left_side ? wall - cover_receiver_overlap : x - half;
  block_right = left_side ? x + half : case_w - wall + cover_receiver_overlap;
  block_bottom = bottom_side ? wall - cover_receiver_overlap : y - half;
  block_top = bottom_side ? y + half : case_h - wall + cover_receiver_overlap;
  z = case_d - back_th - 1.5 - cover_receiver_depth;

  difference() {
    translate([block_left, block_bottom, z])
      cube([block_right - block_left, block_top - block_bottom, cover_receiver_depth]);
    translate([x, y, z - 0.2])
      cylinder(h = cover_receiver_depth + 0.4, d = cover_screw_d);
  }
}

module internal_features() {
  port_tube();

  // Compact rear cover screw receivers.
  for (x = [cover_screw_offset, case_w - cover_screw_offset]) {
    for (y = [cover_screw_offset, case_h - cover_screw_offset]) {
      cover_screw_receiver(x, y);
    }
  }
}

module front_shell() {
  difference() {
    union() {
      front_shell_wall();
      internal_features();
    }

    front_cutouts();
  }
}

module back_cover() {
  difference() {
    union() {
      case_box(case_w, case_h, back_th, corner_r);

      translate([wall + lip_clearance, wall + lip_clearance, back_th - 0.15])
        case_box(
          case_w - wall * 2 - lip_clearance * 2,
          case_h - wall * 2 - lip_clearance * 2,
          lip_depth + 0.15,
          max(corner_r - wall - lip_clearance, 1)
        );
    }

    translate([wall * 2, wall * 2, back_th - 0.2])
      case_box(
        case_w - wall * 4,
        case_h - wall * 4,
        lip_depth + 0.4,
        max(corner_r - wall * 2, 1)
      );

    for (x = [cover_screw_offset, case_w - cover_screw_offset]) {
      for (y = [cover_screw_offset, case_h - cover_screw_offset]) {
        translate([x, y, -0.2])
          cylinder(h = back_th + lip_depth + 0.4, d = cover_screw_d);
      }
    }
  }
}

module port_plug() {
  plug_len = 7.5;
  grip_d = port_d + 7.0;

  union() {
    cylinder(h = plug_len, d = port_d - 0.4);
    translate([0, 0, plug_len - 0.2])
      cylinder(h = 2.0, d = grip_d);
  }
}

if (part_mode == 1) {
  front_shell();
} else if (part_mode == 2) {
  back_cover();
} else if (part_mode == 3) {
  port_plug();
} else {
  front_shell();
  translate([case_w + 10, 0, 0]) back_cover();
  translate([case_w * 2 + 25, 25, 0]) port_plug();
}

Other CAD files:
speaker_cabinet/daiso_4ohm/ダイソー系toilet_bgm_speaker_tuned_front_cabinet.3mf

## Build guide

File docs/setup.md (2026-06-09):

# Setup Notes

## 現在の段階

PlatformIO初期ファームウェア作成済み。COM24への書き込み、OLED表示、KY-040操作、WNYC音出しまで実機確認済み。

## 開発環境候補

- PlatformIO
- Arduino IDE
- Arduino framework for ESP32
- `schreibfaul1/ESP32-audioI2S`

PlatformIOで始める場合、秘密情報は `include/config.local.h` などgit対象外ファイルへ分離する。

このrepoでは `platformio.ini` の `esp32_s3_n16r8` 環境を初期実験用にする。

- Board base: `esp32-s3-devkitc-1`
- Flash: 16MB想定
- PSRAM: N16R8相当として `qio_opi` / `BOARD_HAS_PSRAM`
- Upload/monitor port: `COM24`
- Upload speed: `115200`。USB接続の安定確認を優先し、初期実験では高速化しない。
- Audio library: `schreibfaul1/ESP32-audioI2S`
- Display library: `Adafruit SSD1306` / `Adafruit GFX Library`
- Platform: `pioarduino/platform-espressif32` stable package。`ESP32-audioI2S` 3.x がC++20系のヘッダを使うため、標準のPlatformIO `espressif32` より新しいArduino-ESP32 3系相当を使う。
- Build workaround: `ESP32-audioI2S` 3.4.6 の `<optional>` include漏れを避けるため `-I include` と `-include optional` を指定する。Cファイルにもflagが当たるため、`include/optional` のshimでC++時だけ標準 `<optional>` へ渡す。

## PlatformIOビルド環境の固定方針

このrepoのビルドでは、可能なら共通の固定PlatformIO環境を使う。

グローバルPython 3.14上の `pio` は、PlatformIOやPIOArduino側の依存解決で失敗することがあるため、Python 3.11または3.12の専用venvに入れた `pio.exe` を優先する。

`platformio.ini` の `platform` は現時点では `pioarduino/platform-espressif32` のstable packageを使っているが、再現性が必要になった段階では固定バージョンまたは固定コミットへ寄せる。

`pio run` がC++コンパイル前に失敗した場合は、ソース修正の失敗と決めつけず、PlatformIO環境側の問題として切り分ける。例: `FRAMEWORK_DIR` が `None` になる、framework packageのパス解決で落ちる、Tool Managerの再取得直後に落ちる。

2026-06-08時点で、このrepoでは以下の固定PlatformIO環境でビルドとCOM24アップロードに成功した。

```powershell
$env:PLATFORMIO_CORE_DIR = 'D:\data\codex\tools\platformio-core-py312'
$env:PYTHONUTF8 = '1'
$env:PYTHONIOENCODING = 'utf-8'
& 'D:\data\codex\tools\platformio-py312\Scripts\pio.exe' run
& 'D:\data\codex\tools\platformio-py312\Scripts\pio.exe' run -t upload
```

- Python: `D:\data\codex\tools\platformio-py312\Scripts\python.exe` / Python 3.12.13
- PlatformIO: `D:\data\codex\tools\platformio-py312\Scripts\pio.exe` / PlatformIO Core 6.1.19
- PlatformIO Core Dir: `D:\data\codex\tools\platformio-core-py312`
- 切り分け結果: グローバルPython 3.14側の `pio run` はC++コンパイル前に `FRAMEWORK_DIR` が `None` になる環境エラーで失敗したが、固定Python 3.12環境ではC++コンパイル、firmware生成、COM24アップロードまで成功した。

掃除はソースを消さない範囲から行う。

```powershell
Remove-Item -Recurse -Force .pio
pio system prune --dry-run
```

`pio system prune --dry-run` の内容を確認して問題なければ、必要に応じて `pio system prune` を実行する。

## 最小実験の入口

1. Windowsでは現在 `COM24` として見えている。接続前に毎回COMポートは再確認する。
2. MAX98357Aを `GPIO4/5/6` 仮配線で接続する。
3. 53mm / 4Ω / 3W フルレンジスピーカーをMAX98357Aの `SPK+` / `SPK-` へ接続する。
4. `pio run -t upload` で最小スケッチを書き込む。
5. `pio device monitor -p COM24 -b 115200` でSerialログを見る。
6. OLEDに `esp32_radio`、局名、音量、状態、IPが出るか確認する。
7. KY-040の回転で音量、短押しで局送りが動くか確認する。
8. `ESP.getPsramSize()` / Flash size / Wi-Fi接続先 / codec / エラー / 再接続状況をSerialで確認する。
9. WNYC `https://fm939.wnyc.org/wnycfm` の音が出るか確認する。SD/MODEを3.3Vへ接続した状態で音出し確認済み。
10. 音量は低めから開始する。

## 2026-06-02 実機ログメモ

- COM24への書き込みは、USBケーブル交換後に成功した。
- ESP32-S3 rev 2、Flash 16MB、PSRAM 8MBをSerialで確認済み。
- OLEDはI2C scanで `0x3C` を検出し、SSD1306として初期化成功。
- WNYCはSSL接続、MP3デコード初期化、`stream ready` まで確認。
- BBC Radio 4の旧HLS URLは `410 Gone` になったため、局URLを差し替えた。
- NHK R1はDNS失敗が一度出たため再確認する。
- ABC News / NHK R1 などのHLS局は、接続中に操作が長く止まることがあるため、初期音出しが終わるまではWNYCだけを局送り対象にする。
- MAX98357AのGAINはオープンでよい。SD/MODEはオープンにせず、初期確認では3.3Vへ接続してアンプをONにする。
- OLED表示は、上半分を局名の大きい表示、中央を中サイズの音量表示、最下段を小さいストリーム/IP状態表示にする。
- OLEDの局名/音量はFreeSans系フォントを使う。最下段は小さいデフォルトフォントのまま、`stream ok` など短い状態だけを出す。
- WNYCが無音になる場合、OLED下段が `stream ok` のままならI2S/アンプ/電源側、`stream lost` や再接続表示ならネットワーク/ストリーム側を疑う。
- KY-040クリックは選曲。未検証局は `not tested` と表示し、WNYC以外のHLS局は音出し安定まで自動接続しない。
- BBC Radio 4は、WNYCの次に有効化した実機テストで音出しOK。
- ABC NewsRadioは古い `2038310/.../master.m3u8` では404/無音だったが、AAC-LC 44.1kHz monoのmedia playlist `https://mediaserviceslive.akamaized.net/hls/live/2109425/newsradio/v0-221.m3u8` へ直結して音出しOK。
- NHK R1はpi_radio実績URLへ戻すとPC側ではAAC/HLSとして検出できるが、media playlistに `EXT-X-KEY:METHOD=AES-128` が含まれる。ESP32実機ではまだ音が出ず、NHKは配信方式変更も多いため常用局から外す。
- 常用確認版ではWNYC/BBC/ABCの3局だけを有効化し、KY-040短押しも3局トグルにする。`audio.setConnectionTimeout(1000, 2500)` 追加後は、ABC/NHK選局時の長時間フリーズは解消した。
- stoppedから復帰するとき、OLED下段に `wake...` を出し、SPIFFS上の `data/wake.m4a` を音量15で鳴らす。音源は `skysea_sound_pack/reserve_notice.m4a` を採用した。
- 効果音ファイルを更新した場合は、通常の `pio run -t upload` だけでなく `pio run -t uploadfs` も実行する。
- KY-040長押しで通信停止/待機へ入る。停止中はOLEDの音量表示位置に `stopped`、下段に `wifi off` を出し、Wi-FiをOFFにする。KY-040を回す、または押すと復帰する。実機確認済み。
- 2026-06-02時点では `pi_radio` のスピーカーを流用中。注文済みスピーカー到着後、2026-06-05ごろに起動時音量と復帰効果音音量を耳で再調整する。

## Wi-Fi設定

初期実験では、SSIDを固定文字列で決め打ちしない。
同じ家・同じ用途で複数SSIDがあるため、ローカル設定に入れたSSID prefixだけを候補にし、ESP32 Arduinoの `Preferences` で前回接続に成功したSSIDをNVSへ保存する。

推奨:

- `include/config.local.h` にローカルSSID prefix/passwordを置く。
- `include/config.example.h` にはダミー値だけ置く。
- `.gitignore` で `config.local.h` を除外する。
- 接続成功したSSIDは `Preferences` namespace `wifi` の `last_ssid` に保存する。

接続候補の優先順位:

1. 周囲のSSIDを `WiFi.scanNetworks()` で走査する。
2. 設定したprefixで始まるSSIDだけを候補にする。
3. NVSに保存された前回成功SSIDが見つかれば最優先する。
4. 見つからなければ、設定済みの優先SSIDを見る。
5. それもなければ、prefix一致SSIDのうちRSSIが一番強いものを選ぶ。
6. 接続に成功したSSIDを再び `last_ssid` として保存する。

実装時の要点:

```cpp
Preferences wifiPrefs;

wifiPrefs.begin("wifi", true);
String lastSsid = wifiPrefs.getString("last_ssid", "");
wifiPrefs.end();

int networkCount = WiFi.scanNetworks();
```

```cpp
wifiPrefs.begin("wifi", false);
wifiPrefs.putString("last_ssid", connectedSsid);
wifiPrefs.end();
```

## 友人配布向けの設定構想

友人へ渡す段階では、コードを書き換えなくてもWi-Fiと局URLを変えられるようにしたい。

候補:

1. SoftAP + Web設定画面。
2. ESP32-S3のUSB MSC設定モードで、PCから `WIFI.TXT` / `STATIONS.TXT` を編集する。

現時点では、USB MSC方式を「最後に試す面白い構想」として残す。詳細は `docs/usb_msc_config_plan.md` を参照する。

## Web設定画面

初期実験では作らない。

理由:

- まず音声再生とHLS/AAC可否を切り分ける。
- Web設定、DNS、NVS保存を同時に入れると原因切り分けが難しくなる。

追加するなら、WNYC/BBC/ABCの3局運用が安定した後にSoftAP + Web設定、またはUSB MSC TXT設定モードとして設計する。

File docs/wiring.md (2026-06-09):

# Wiring Notes

## 初期方針

ESP32-S3、MAX98357A、OLED、ロータリーエンコーダを接続済みとして扱う。
初期スケッチでは、OLEDへ状態/IP/音量を出し、KY-040で音量変更と局送りを行う。

## MAX98357A I2S

| MAX98357A | ESP32-S3 GPIO案 | 役割 |
|---|---:|---|
| VIN | 5V | 電源 |
| GND | GND | 共通GND |
| DIN | GPIO4 | I2S data out |
| BCLK | GPIO5 | I2S bit clock |
| LRC / LRCLK / WS | GPIO6 | I2S left/right clock |
| GAIN | 未接続 | まず既定gain |
| SD / MODE | 3.3V | 初期音出しでは強制ON。オープンだと基板によって無音になり得る |
| SPK+ / SPK- | 53mm / 4Ω / 3W speaker | GNDへ接続しない |

このGPIO案は仮。実ボードのピン表確認後に確定する。

2026-06-01に今回使うESP32-S3-WROOM-1 N16R8基板とMAX98357Aの表裏写真を共有資産として保存した。
配線を確定するときは `D:\data\codex\shared_assets\hardware\esp32_radio\20260601_board_photos` の表裏写真でシルク印字を確認する。

## OLED

`pi_radio` と同じ GM009606v4.3 OLED を使う。`pi_radio` では `SSD1306 128x64 / I2C 0x3C` として点灯確認済み。

| OLED | ESP32-S3 GPIO案 | 備考 |
|---|---:|---|
| SDA | GPIO8 | 初期実装 |
| SCL | GPIO9 | 初期実装 |
| VCC | 3.3V | モジュール仕様確認 |
| GND | GND | 共通GND |

`SCK` 表記の端子がある場合はI2Cの `SCL` として扱う。

## KY-040候補

| KY-040 | ESP32-S3 GPIO案 | 備考 |
|---|---:|---|
| CLK / A | GPIO10 | 初期実装。内部pull-up |
| DT / B | GPIO11 | 初期実装。内部pull-up |
| SW | GPIO12 | 初期実装。内部pull-up |
| + | 3.3V | モジュール仕様確認 |
| GND | GND | 共通GND |

## 18650 + TP4056 + XL6009E1試作配線

2026-06-06時点の手持ち部品では、緑TP4056 USB-C基板とXL6009E1昇圧モジュールで1セル18650駆動を試す。

```text
18650 +
  -> 緑TP4056 B+

18650 -
  -> 緑TP4056 B-

緑TP4056 OUT+
  -> 電源スイッチ
  -> XL6009E1 IN+

緑TP4056 OUT-
  -> XL6009E1 IN-

XL6009E1 OUT+
  -> ESP32-S3 5V
  -> MAX98357A VIN

XL6009E1 OUT-
  -> ESP32-S3 GND
  -> MAX98357A GND
```

注意:

- ESP32-S3やMAX98357Aへ接続する前に、XL6009E1の出力をテスターで5.0V前後へ調整する。
- TP4056基板はpower pathではないため、まずは電源OFFで充電し、使用時は充電USBを外す。
- 電池残量表示を入れる場合は、XL6009E1の5V出力側ではなく、緑TP4056の`OUT+` / `OUT-`側または電池側を抵抗分圧してESP32-S3 ADCへ入れる。
- 保護基板の過放電カットまで使い切らず、OLED上で低残量を表示して早めに停止する。

## 電池残量ADC

2026-06-07時点の実装では、GPIO1を18650電圧のADC入力として使う。

```text
XL6009E1 IN+ 側、スイッチ後の電池電圧
  -> 100kΩ
  -> GPIO1
  -> 100kΩ
  -> GND
```

GPIO1とGNDの間に0.1uF程度を入れると表示が安定しやすい。ファームウェア側では `analogReadMilliVolts(GPIO1)` を読み、分圧比2.0倍で電池電圧へ戻してOLED右下に `Bxx%` と表示する。

実機ではGPIO1とGNDの間に10uFセラミックコンデンサを追加した。コンデンサなしではADC由来の残量表示が少しふらついたが、10uF追加後は表示の揺れがかなり減り、実用上落ち着いた。OLED上の残量表示は音量行の右側へ大きめに出し、約7秒ごとに更新する。前回表示から1%以内の変化なら表示を維持してちらつきを抑える。

## 購入済み充放電統合モジュールの試験予定

2026-06-06に、1S Li-ion充放電統合モジュール Type-C / 5V 2A を5個購入した。到着予定は2026-06-10から2026-06-12。到着後は、TP4056 + XL6009E1の代替として以下を試す。

```text
18650 +
  -> 充放電統合モジュール B+

18650 -
  -> 充放電統合モジュール B-

充放電統合モジュール 5V+
  -> ESP32-S3 5V
  -> MAX98357A VIN

充放電統合モジュール 5V-
  -> ESP32-S3 GND
  -> MAX98357A GND
```

到着後の確認:

- 4.2V充電設定になっていること。普通の18650を4.35V設定で充電しない。
- 無負荷、再生中、充電USB接続中、充電USB取り外し時の5V出力を測る。
- `stopped` / Wi-Fi OFF状態で、50mA未満自動OFFに入るか確認する。
- K端子で外部電源スイッチ化できるか確認する。

## 配線時の注意

- I2S線は短めにする。
- アンプとESP32のGNDは必ず共通にする。
- スピーカー出力は53mm / 4Ω / 3Wフルレンジスピーカーへつなぐ。
- スピーカー出力をGNDやイヤホン入力へつながない。
- 音が割れる場合はソフト音量を下げ、GAIN設定と電源容量を見直す。
- GAINオープンはデフォルト9dBなので初期実験ではそのままでよい。
- SD/MODEはシャットダウン兼チャンネル選択。最初の音出しでは3.3Vへ接続してアンプを確実にONにする。
- SD/MODEをGNDへ落とすとシャットダウンになる。オープンはモジュール実装によって不安定なので、無音時はまずSD/MODEを疑う。

## 音質と電源まわり

- `pi_radio` と同じスピーカーを流用しているため、音質差の主因はスピーカーそのものより MAX98357A、5V/GND配線、電源安定性、ESP32側の負荷と見る。
- MAX98357Aの `VIN` は5V、`GND` はESP32と共通、`SD/MODE` は3.3Vで強制ONにする。`SD/MODE` オープンは無音原因になり得る。
- `GAIN` はオープンのままでよい。音量不足や音割れが明確になった場合にだけ変更を検討する。
- 最初の音質改善は、スピーカー固定、筐体、5V/GNDの短く太い配線、USB電源の余裕、I2S配線の取り回しから確認する。
- `PCM5102A + PAM8403` は音質改善候補だが、部品点数、配線、電源、コストが増えるため現時点では保留し、MAX98357A構成を継続する。

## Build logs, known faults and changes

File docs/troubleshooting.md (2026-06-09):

# Troubleshooting Notes

## PSRAMが見えない

症状:

- 起動ログでPSRAM容量が0。
- `ESP32-audioI2S` の初期化や再生中にクラッシュする。

確認:

- ボード型番にPSRAMがあるか。
- PlatformIO/Arduinoのボード設定がPSRAM有効になっているか。
- `ESP.getPsramSize()` の値。

## WNYCが鳴らない

確認:

- Wi-Fi接続できているか。
- IPアドレスが出ているか。
- `https://fm939.wnyc.org/wnycfm` へ接続ログが出ているか。
- 音量が0ではないか。
- MAX98357Aの `DIN/BCLK/LRC` が逆になっていないか。
- スピーカーを `SPK+` / `SPK-` に接続しているか。

## BBC / ABC が鳴らない

原因候補:

- HLS `.m3u8` の処理に失敗。
- HTTPS/TLSやリダイレクトで失敗。
- 放送局側URLが変わった。
- セグメント取得中にバッファ不足。

切り分け:

- WNYC MP3直ストリームが鳴る状態で1局ずつ試す。
- Serialログの最後のURL、HTTP status、codec表示を見る。
- 可能ならPCの `ffprobe` で同日URLを再確認する。

## ノイズ・音割れ

確認:

- ソフト音量を下げる。
- MAX98357AのGAIN設定を下げる。
- 5V電源の電流容量を確認する。
- I2S配線を短くする。
- GNDを共通化する。

## 電源スイッチ初回ONで起動せず、OFF→ONで起動する

原因候補:

- TP4056保護回路、XL6009E1昇圧モジュール、ESP32-S3、MAX98357Aの起動時突入電流が重なり、初回ONで5Vが十分に立ち上がらない。
- XL6009E1のソフトスタートや出力コンデンサ充電中にESP32-S3がブラウンアウト気味になり、リセット条件が中途半端になる。
- いったんOFFにすると昇圧側のコンデンサや保護回路状態が変わり、2回目ONでは5V立ち上がりが安定して起動できる。
- 電池電圧が低い、スイッチ接点抵抗が高い、5V/GND配線が細い/長い場合に起きやすい。

切り分け:

- 初回ON直後と2回目ON直後で、XL6009E1 OUT+ / OUT- の5Vが何Vまで落ちるかテスターで見る。
- 緑TP4056 OUT+ / OUT- 側の電池電圧も同時に確認し、保護回路側で電圧が落ちていないか見る。
- USB 5V直給電では一発起動するか確認する。一発起動するならファームより電源立ち上がり側が濃厚。
- 音量を下げた状態、MAX98357Aを一時的に外した状態で一発起動するか確認する。
- 5V/GND配線を短く太くし、スイッチ接点とハンダを確認する。

対策候補:

- XL6009E1出力側、ESP32-S3近くに470uF程度の低ESR電解コンデンサを追加して5V立ち上がりを支える。
- ESP32-S3のEN/RSTに適切な遅延リセットを入れ、5Vが安定してから起動させる。
- 到着予定の1S Li-ion充放電統合モジュール Type-C / 5V 2Aへ置き換え、5V立ち上がり、再生中電圧、発熱、自動OFFを実測する。
- 初回ONで不安定なまま運用しない。ブラウンアウト状態での起動失敗はファイル設定やI2C初期化失敗の見かけ原因にもなり得る。

470uF追加後の観察:

- バッテリー昇圧起動時に、OLEDが格子状/バグったような未初期化表示を出してから起動することがある。
- USB 5V直給電では出ないため、表示器単体故障よりも、TP4056 + XL6009E1 + 470uF構成での5V立ち上がりが遅く、OLEDがESP32-S3のI2C初期化より先に点灯している可能性が高い。
- ファームウェア側では、起動直後のSerial待ちを短くし、OLED初期化/クリアをできるだけ早く実行する。
- それでも残る場合は、OLEDのVCCをESP32-S3側の3.3Vから取っているか、昇圧5V側から直接取っているかを確認する。OLEDがESP32より先に電源ONになる配線だと未初期化表示が出やすい。

同じ症状が続く場合:

- OLEDが一瞬だけ格子状表示を出して、その後に通常表示へ戻るだけなら、OLEDコントローラがESP32-S3のI2C初期化前に点灯している症状として扱う。SSD1306系OLEDにRESET線を配線していない構成では、完全にゼロにはしにくい。
- 格子状表示のままフリーズする、または音声/Wi-Fi起動まで進まない場合は、OLEDではなくESP32-S3側のブラウンアウト/不完全リセットを疑う。
- 470uF追加で起動不能から「バグ表示後に起動」へ変わった場合、電源保持は改善しているが、昇圧モジュールの起動負荷も増えている可能性がある。100uFから220uFへ下げて比較する。
- 470uFを残す場合は、OFF時にコンデンサ電荷が残ることで次回起動状態が変わる可能性がある。必要なら5V-GND間に4.7kΩから10kΩ程度のブリーダ抵抗を入れ、OFF後にゆっくり放電させる。ただし常時0.5mAから1mA程度の無駄電流が増える。
- ESP32-S3のEN/RST端子へ1uFから10uF程度をGNDへ追加し、5V/3.3Vが安定してからESP32-S3を起動させる方法を次候補にする。EN端子の位置と既存プルアップを確認してから試す。
- 到着予定の1S Li-ion充放電統合モジュールでは、同じ470uF有無、EN遅延有無、COM24シリアルログ有無で比較する。

2026-06-09のソフト回避実験:

- `POWER_SETTLE_RESTART_ENABLED=true` として、`ESP_RST_POWERON` または `ESP_RST_BROWNOUT` の直後だけ1500ms待って `ESP.restart()` する処理を追加した。
- 目的は、電源投入直後の不安定な1回目の起動を捨て、5V/3.3Vが安定した後のソフトリセット起動に寄せること。
- この処理で改善する場合は、手動RESETボタンを押したときに起動する症状と同じ系統と見る。
- この処理でも全く改善しない場合は、アプリの `setup()` まで到達していない可能性が高く、ソフトdelayではなく電源モジュール、EN/RST外付け遅延、または昇圧モジュール交換を優先する。

RESETボタンでも無反応の場合:

- ESP32-S3開発キット上のRESET/ENボタンを押しても、OLEDの格子状表示が残ったまま何も変わらない場合、ファームウェアやソフトリセットでは回避できない状態と見る。
- この状態ではOLEDだけが半端に給電され、ESP32-S3本体は正常に起動できる5V/3.3V/EN条件に入っていない可能性が高い。
- まず追加したEN/RST-GND間の10uFを外し、ESP32-S3の5Vピン、3.3Vピン、ENピンの電圧を電源ON直後と安定後で測る。
- 5Vが4.8V未満、3.3Vが3.0V台前半以下、またはENがHIGHへ上がっていない場合は、XL6009E1/TP4056/配線/スイッチ側の電源問題として扱う。
- USB直給電では正常に起動し、バッテリー昇圧だけでRESET無反応になるなら、現行のTP4056 + XL6009E1構成はこの負荷に対して起動シーケンスが不安定と判断する。

RESETボタンで正常起動する場合:

- 追加コンデンサを外した状態で、5V、3.3V、ENが正常電圧なのに、電源投入直後だけOLEDが格子状表示のまま止まり、ESP32-S3開発キット上のRESETボタンを押すと正常起動することを確認した。
- この場合は電源容量不足よりも、電源投入時の初回リセット/ブートシーケンス不良として扱う。
- ソフトウェア上の `delay()` や `ESP.restart()` は、アプリの `setup()` まで到達しない初回不完全起動には効かない。`POWER_SETTLE_RESTART_ENABLED` は無効化する。
- 本命対策は、電源投入後にESP32-S3のEN/RSTへ確実なハードリセットパルスを入れること。簡易RC遅延で不安定なら、リセット監視ICや1S充放電統合モジュール側の安定した5V出力へ切り替える。

## WNYCがstream okなのに無音になる

確認:

- OLED下段が `stream ok` のままなら、ストリーム取得より後段のI2S/アンプ/電源側を疑う。
- OLED下段が `stream lost`、`tuning...`、再接続表示へ変わるなら、Wi-Fi、DNS、局側ストリーム、`audio.connecttohost()` のブロックを疑う。
- Serialログで codec / bitrate / slow stream / reconnect の有無を見る。
- MAX98357Aの `SD/MODE` が3.3Vへ接続されているか確認する。オープンは無音原因になり得る。
- `GAIN` はオープンでよい。まずはソフト音量、5V/GND配線、電源容量、スピーカー固定を確認する。

## 音質がpi_radioより少し悪く感じる

確認:

- 現時点では決定的な差とは判断しない。
- 同じスピーカーを使っているため、差分要因は MAX98357A、ESP32側の負荷、5V/GND配線、電源安定性、筐体/スピーカー固定を優先して見る。
- `PCM5102A + PAM8403` は音質改善候補だが、今回は部品と配線とコストが増えるため保留する。
- まずはMAX98357A構成のまま、筐体、固定、配線、電源で改善余地を見る。

## OLED追加後に音が途切れる

原因候補:

- 描画更新が頻繁すぎる。
- I2C処理が音声loopを邪魔している。
- Serialログや画面更新が多すぎる。

対策:

- OLED更新を1秒に1回程度へ制限する。
- 音声処理loopを止めない。
- 表示内容を最小限にする。

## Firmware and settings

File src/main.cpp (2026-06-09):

#include <Arduino.h>
#include <Adafruit_GFX.h>
#include <Adafruit_SSD1306.h>
#include <Audio.h>
#include <Fonts/FreeSans12pt7b.h>
#include <Fonts/FreeSans9pt7b.h>
#include <Fonts/FreeSansBold12pt7b.h>
#include <Preferences.h>
#include <SPIFFS.h>
#include <WiFi.h>
#include <Wire.h>
#include <esp_system.h>

#if __has_include("config.local.h")
#include "config.local.h"
#else
#include "config.example.h"
#endif

namespace {

constexpr int I2S_DOUT_PIN = 4;
constexpr int I2S_BCLK_PIN = 5;
constexpr int I2S_LRC_PIN = 6;

constexpr int OLED_SDA_PIN = 8;
constexpr int OLED_SCL_PIN = 9;
constexpr uint8_t OLED_ADDR = 0x3C;
constexpr int OLED_WIDTH = 128;
constexpr int OLED_HEIGHT = 64;

constexpr int ROTARY_CLK_PIN = 10;
constexpr int ROTARY_DT_PIN = 11;
constexpr int ROTARY_SW_PIN = 12;

constexpr int BATTERY_ADC_PIN = 1;
constexpr float BATTERY_DIVIDER_RATIO = 2.0f;
constexpr unsigned long BATTERY_READ_MS = 7000;
constexpr uint8_t BATTERY_SAMPLE_COUNT = 8;
constexpr uint8_t BATTERY_PERCENT_HYSTERESIS = 1;

constexpr uint8_t AUDIO_VOLUME_MIN = 0;
constexpr uint8_t AUDIO_VOLUME_MAX = 21;
constexpr uint8_t AUDIO_VOLUME_INITIAL = 3;
constexpr unsigned long WIFI_CONNECT_TIMEOUT_MS = 15000;
constexpr unsigned long DISPLAY_UPDATE_MS = 750;
constexpr unsigned long OLED_RETRY_MS = 3000;
constexpr bool POWER_SETTLE_RESTART_ENABLED = false;
constexpr unsigned long POWER_SETTLE_RESTART_DELAY_MS = 1500;
constexpr unsigned long BUTTON_DEBOUNCE_MS = 250;
constexpr unsigned long BUTTON_LONG_PRESS_MS = 1500;
constexpr unsigned long AUDIO_RETRY_MS = 15000;
constexpr unsigned long AUDIO_RUNNING_GRACE_MS = 10000;
constexpr uint16_t AUDIO_CONNECT_TIMEOUT_MS = 1000;
constexpr uint16_t AUDIO_CONNECT_TIMEOUT_SSL_MS = 2500;
constexpr uint8_t WAKE_EFFECT_VOLUME = 15;
constexpr unsigned long WAKE_EFFECT_TIMEOUT_MS = 6000;
constexpr const char* WAKE_EFFECT_PATH = "/wake.m4a";

struct Station {
  const char* name;
  const char* url;
  bool enabled;
};

Station stations[] = {
    {"WNYC FM", "https://fm939.wnyc.org/wnycfm", true},
    {"BBC R4", "https://a.files.bbci.co.uk/ms6/live/3441A116-B12E-4D2F-ACA8-C1984642FA4B/audio/simulcast/hls/nonuk/audio_syndication_low_sbr_v1/cfs/bbc_radio_fourfm.m3u8", true},
    {"ABC", "https://mediaserviceslive.akamaized.net/hls/live/2109425/newsradio/v0-221.m3u8", true},
};

Audio audio;
Preferences wifiPrefs;
Adafruit_SSD1306 display(OLED_WIDTH, OLED_HEIGHT, &Wire, -1);

uint8_t currentVolume = AUDIO_VOLUME_INITIAL;
int currentStation = 0;
bool oledReady = false;
String statusLine = "boot";
String audioLine = "idle";
String wifiSsid = "";
String wifiIp = "";
int lastRotaryClk = HIGH;
unsigned long lastDisplayUpdate = 0;
unsigned long lastButtonAt = 0;
unsigned long lastAudioRetryAt = 0;
unsigned long lastStreamOkAt = 0;
bool streamWasRunning = false;
bool stoppedMode = false;
bool buttonWasPressed = false;
bool longPressHandled = false;
unsigned long buttonPressedAt = 0;
bool effectsReady = false;
float batteryVoltage = 0.0f;
int batteryPercent = -1;
unsigned long lastBatteryReadAt = 0;
unsigned long lastOledRetryAt = 0;

struct BatteryPoint {
  float voltage;
  uint8_t percent;
};

constexpr BatteryPoint BATTERY_CURVE[] = {
    {3.20f, 0},
    {3.30f, 5},
    {3.50f, 20},
    {3.70f, 40},
    {3.85f, 60},
    {4.00f, 80},
    {4.10f, 90},
    {4.20f, 100},
};

struct WifiCandidate {
  String ssid;
  int32_t rssi = -127;
};

void setStatus(const String& line) {
  statusLine = line;
  Serial.printf("[status] %s\n", statusLine.c_str());
}

void setAudioLine(const String& line) {
  audioLine = line;
  Serial.printf("[audio] %s\n", audioLine.c_str());
}

void maybeRestartAfterPowerSettle() {
  if (!POWER_SETTLE_RESTART_ENABLED) {
    return;
  }

  esp_reset_reason_t reason = esp_reset_reason();
  Serial.printf("[boot] reset reason=%d\n", static_cast<int>(reason));
  if (reason != ESP_RST_POWERON && reason != ESP_RST_BROWNOUT) {
    return;
  }

  Serial.printf("[boot] waiting %lu ms before one-shot soft restart\n", POWER_SETTLE_RESTART_DELAY_MS);
  delay(POWER_SETTLE_RESTART_DELAY_MS);
  Serial.println("[boot] restarting after power settle");
  Serial.flush();
  delay(100);
  ESP.restart();
}

int batteryPercentFromVoltage(float voltage) {
  if (voltage <= BATTERY_CURVE[0].voltage) {
    return BATTERY_CURVE[0].percent;
  }

  constexpr int curveCount = static_cast<int>(sizeof(BATTERY_CURVE) / sizeof(BATTERY_CURVE[0]));
  for (int i = 1; i < curveCount; ++i) {
    if (voltage <= BATTERY_CURVE[i].voltage) {
      const BatteryPoint& low = BATTERY_CURVE[i - 1];
      const BatteryPoint& high = BATTERY_CURVE[i];
      float t = (voltage - low.voltage) / (high.voltage - low.voltage);
      return static_cast<int>(roundf(low.percent + t * (high.percent - low.percent)));
    }
  }

  return BATTERY_CURVE[curveCount - 1].percent;
}

void readBattery(bool force = false) {
  unsigned long now = millis();
  if (!force && now - lastBatteryReadAt < BATTERY_READ_MS) {
    return;
  }
  lastBatteryReadAt = now;

  uint32_t totalMv = 0;
  for (uint8_t i = 0; i < BATTERY_SAMPLE_COUNT; ++i) {
    totalMv += analogReadMilliVolts(BATTERY_ADC_PIN);
    delay(2);
  }

  float adcVoltage = (totalMv / static_cast<float>(BATTERY_SAMPLE_COUNT)) / 1000.0f;
  batteryVoltage = adcVoltage * BATTERY_DIVIDER_RATIO;
  int measuredPercent = constrain(batteryPercentFromVoltage(batteryVoltage), 0, 100);
  if (batteryPercent < 0 || abs(measuredPercent - batteryPercent) > BATTERY_PERCENT_HYSTERESIS) {
    batteryPercent = measuredPercent;
  }
}

String readLastSsid() {
  wifiPrefs.begin("wifi", true);
  String ssid = wifiPrefs.getString("last_ssid", "");
  wifiPrefs.end();
  return ssid;
}

void saveLastSsid(const String& ssid) {
  wifiPrefs.begin("wifi", false);
  wifiPrefs.putString("last_ssid", ssid);
  wifiPrefs.end();
}

bool appendUnique(WifiCandidate* candidates, int& count, const String& ssid, int32_t rssi) {
  if (ssid.isEmpty()) {
    return false;
  }

  for (int i = 0; i < count; ++i) {
    if (candidates[i].ssid == ssid) {
      if (rssi > candidates[i].rssi) {
        candidates[i].rssi = rssi;
      }
      return false;
    }
  }

  candidates[count++] = {ssid, rssi};
  return true;
}

void sortByRssiDesc(WifiCandidate* candidates, int count) {
  for (int i = 0; i < count - 1; ++i) {
    for (int j = i + 1; j < count; ++j) {
      if (candidates[j].rssi > candidates[i].rssi) {
        WifiCandidate tmp = candidates[i];
        candidates[i] = candidates[j];
        candidates[j] = tmp;
      }
    }
  }
}

void drawDisplay(bool force = false) {
  if (!oledReady) {
    return;
  }
  if (!force && millis() - lastDisplayUpdate < DISPLAY_UPDATE_MS) {
    return;
  }
  lastDisplayUpdate = millis();

  display.clearDisplay();
  display.setTextColor(SSD1306_WHITE);

  display.setFont(&FreeSansBold12pt7b);
  display.setCursor(0, 22);
  display.print(stations[currentStation].name);

  display.setFont(&FreeSans12pt7b);
  display.setCursor(0, 45);
  if (stoppedMode) {
    display.print("stopped");
  } else {
    display.print("Vol ");
    display.print(currentVolume);
  }
  display.setFont(&FreeSans9pt7b);
  display.setCursor(76, 45);
  if (batteryPercent >= 0) {
    display.print(batteryPercent);
    display.print("%");
  } else {
    display.print("--%");
  }

  display.setFont(nullptr);
  display.setTextSize(1);
  display.setCursor(0, 52);
  String stream = audioLine.isEmpty() ? statusLine : audioLine;
  display.print(stream.substring(0, 21));
  display.display();
}

bool beginOled() {
  oledReady = display.begin(SSD1306_SWITCHCAPVCC, OLED_ADDR);
  if (!oledReady) {
    Serial.printf("[oled] not found at 0x%02X\n", OLED_ADDR);
    return false;
  }

  Serial.printf("[oled] ready at 0x%02X SDA=%d SCL=%d\n", OLED_ADDR, OLED_SDA_PIN, OLED_SCL_PIN);
  display.clearDisplay();
  display.display();
  drawDisplay(true);
  return true;
}

void scanI2c() {
  Serial.println("[i2c] scanning");
  for (uint8_t address = 1; address < 127; ++address) {
    Wire.beginTransmission(address);
    if (Wire.endTransmission() == 0) {
      Serial.printf("[i2c] found 0x%02X\n", address);
    }
  }
}

void setupOled() {
  Wire.begin(OLED_SDA_PIN, OLED_SCL_PIN);
  delay(100);

  for (uint8_t attempt = 1; attempt <= 3; ++attempt) {
    Serial.printf("[oled] init attempt %u\n", attempt);
    scanI2c();
    if (beginOled()) {
      return;
    }
    delay(250);
  }
  lastOledRetryAt = millis();
}

void maybeRetryOled() {
  if (oledReady || millis() - lastOledRetryAt < OLED_RETRY_MS) {
    return;
  }
  lastOledRetryAt = millis();
  Serial.println("[oled] retry");
  beginOled();
}

void setupEffects() {
  effectsReady = SPIFFS.begin(true);
  if (!effectsReady) {
    Serial.println("[effect] SPIFFS mount failed");
    return;
  }
  if (!SPIFFS.exists(WAKE_EFFECT_PATH)) {
    effectsReady = false;
    Serial.printf("[effect] missing %s\n", WAKE_EFFECT_PATH);
    return;
  }
  File wakeFile = SPIFFS.open(WAKE_EFFECT_PATH, FILE_READ);
  Serial.printf("[effect] wake sound ready: %s size=%u\n", WAKE_EFFECT_PATH, static_cast<unsigned>(wakeFile.size()));
  wakeFile.close();
}

int buildCandidateOrder(WifiCandidate* ordered, int maxCount) {
  String lastSsid = readLastSsid();
  String preferredSsid = WIFI_PREFERRED_SSID;
  WifiCandidate scanned[32];
  int scannedCount = 0;

  setStatus("wifi scan");
  Serial.printf("[wifi] scanning for SSIDs matching prefix '%s'\n", WIFI_SSID_PREFIX);
  int networkCount = WiFi.scanNetworks();
  Serial.printf("[wifi] scan result: %d networks\n", networkCount);

  for (int i = 0; i < networkCount && scannedCount < 32; ++i) {
    String ssid = WiFi.SSID(i);
    if (!ssid.startsWith(WIFI_SSID_PREFIX)) {
      continue;
    }
    appendUnique(scanned, scannedCount, ssid, WiFi.RSSI(i));
    Serial.printf("[wifi] candidate: %s RSSI=%d\n", ssid.c_str(), WiFi.RSSI(i));
  }

  if (scannedCount == 0) {
    Serial.println("[wifi] no matching SSID found");
    WiFi.scanDelete();
    return 0;
  }

  int orderedCount = 0;

  for (int i = 0; i < scannedCount && orderedCount < maxCount; ++i) {
    if (!lastSsid.isEmpty() && scanned[i].ssid == lastSsid) {
      appendUnique(ordered, orderedCount, scanned[i].ssid, scanned[i].rssi);
      Serial.printf("[wifi] priority last_ssid: %s\n", scanned[i].ssid.c_str());
    }
  }

  for (int i = 0; i < scannedCount && orderedCount < maxCount; ++i) {
    if (!preferredSsid.isEmpty() && scanned[i].ssid == preferredSsid) {
      appendUnique(ordered, orderedCount, scanned[i].ssid, scanned[i].rssi);
      Serial.printf("[wifi] priority preferred: %s\n", scanned[i].ssid.c_str());
    }
  }

  sortByRssiDesc(scanned, scannedCount);
  for (int i = 0; i < scannedCount && orderedCount < maxCount; ++i) {
    appendUnique(ordered, orderedCount, scanned[i].ssid, scanned[i].rssi);
  }

  WiFi.scanDelete();
  return orderedCount;
}

bool connectToSsid(const String& ssid) {
  setStatus("wifi connect");
  Serial.printf("[wifi] connecting to %s\n", ssid.c_str());
  WiFi.begin(ssid.c_str(), WIFI_PASSWORD);

  unsigned long startedAt = millis();
  while (WiFi.status() != WL_CONNECTED && millis() - startedAt < WIFI_CONNECT_TIMEOUT_MS) {
    delay(250);
    Serial.print('.');
    drawDisplay();
  }
  Serial.println();

  if (WiFi.status() != WL_CONNECTED) {
    Serial.printf("[wifi] failed: %s\n", ssid.c_str());
    WiFi.disconnect(true, true);
    delay(500);
    return false;
  }

  wifiSsid = ssid;
  wifiIp = WiFi.localIP().toString();
  Serial.printf("[wifi] connected: %s IP=%s RSSI=%d\n", ssid.c_str(), wifiIp.c_str(), WiFi.RSSI());
  saveLastSsid(ssid);
  setStatus("wifi ok");
  drawDisplay(true);
  return true;
}

bool connectWifi() {
  WiFi.mode(WIFI_STA);
  WiFi.setSleep(false);
  WiFi.disconnect(true, true);
  delay(500);

  WifiCandidate ordered[32];
  int orderedCount = buildCandidateOrder(ordered, 32);
  for (int i = 0; i < orderedCount; ++i) {
    if (connectToSsid(ordered[i].ssid)) {
      return true;
    }
  }

  return false;
}

void printBoardInfo() {
  Serial.println();
  Serial.println("=== esp32_radio playback test ===");
  Serial.printf("[board] chip model: %s rev %d\n", ESP.getChipModel(), ESP.getChipRevision());
  Serial.printf("[board] CPU freq: %u MHz\n", ESP.getCpuFreqMHz());
  Serial.printf("[board] flash size: %u bytes\n", ESP.getFlashChipSize());
  Serial.printf("[board] PSRAM size: %u bytes free=%u\n", ESP.getPsramSize(), ESP.getFreePsram());
  Serial.printf("[i2s] DOUT=%d BCLK=%d LRC=%d\n", I2S_DOUT_PIN, I2S_BCLK_PIN, I2S_LRC_PIN);
  Serial.printf("[oled] SDA=%d SCL=%d addr=0x%02X\n", OLED_SDA_PIN, OLED_SCL_PIN, OLED_ADDR);
  Serial.printf("[rotary] CLK=%d DT=%d SW=%d\n", ROTARY_CLK_PIN, ROTARY_DT_PIN, ROTARY_SW_PIN);
  Serial.printf("[battery] ADC GPIO=%d divider=%.2f\n", BATTERY_ADC_PIN, BATTERY_DIVIDER_RATIO);
}

void startAudio() {
  if (stoppedMode) {
    setStatus("stopped");
    setAudioLine("wifi off");
    drawDisplay(true);
    return;
  }
  Station& station = stations[currentStation];
  if (!station.enabled) {
    setStatus("select only");
    setAudioLine("not tested");
    Serial.printf("[audio] station disabled for now: %s\n", station.name);
    drawDisplay(true);
    return;
  }
  setStatus("audio start");
  setAudioLine("tuning...");
  Serial.printf("[audio] station: %s\n", station.name);
  Serial.printf("[audio] url: %s\n", station.url);
  audio.setVolume(currentVolume);
  unsigned long connectStartedAt = millis();
  bool started = audio.connecttohost(station.url);
  unsigned long connectElapsed = millis() - connectStartedAt;
  Serial.printf("[audio] connecttohost result=%s elapsed=%lu ms\n", started ? "true" : "false", connectElapsed);
  lastAudioRetryAt = millis();
  lastStreamOkAt = started ? millis() : 0;
  streamWasRunning = false;
  if (!started) {
    setAudioLine("tune failed");
  }
  drawDisplay(true);
}

void changeStation(int direction) {
  int stationCount = static_cast<int>(sizeof(stations) / sizeof(stations[0]));
  currentStation = (currentStation + direction + stationCount) % stationCount;
  Serial.printf("[station] selected %d: %s\n", currentStation, stations[currentStation].name);
  if (stoppedMode) {
    setStatus("stopped");
    setAudioLine("wifi off");
    drawDisplay(true);
    return;
  }
  if (audio.isRunning()) {
    audio.stopSong();
  }
  startAudio();
}

void enterStoppedMode() {
  if (stoppedMode) {
    return;
  }
  Serial.println("[control] entering stopped mode");
  if (audio.isRunning()) {
    audio.stopSong();
  } else {
    audio.stopSong();
  }
  WiFi.disconnect(false);
  WiFi.mode(WIFI_OFF);
  stoppedMode = true;
  streamWasRunning = false;
  lastStreamOkAt = 0;
  setStatus("stopped");
  setAudioLine("wifi off");
  drawDisplay(true);
}

void playWakeEffect() {
  if (!effectsReady) {
    Serial.println("[effect] wake sound skipped");
    return;
  }

  Serial.printf("[effect] wake sound start: %s volume=%u\n", WAKE_EFFECT_PATH, WAKE_EFFECT_VOLUME);
  audio.stopSong();
  audio.setVolume(WAKE_EFFECT_VOLUME);

  if (!audio.connecttoFS(SPIFFS, WAKE_EFFECT_PATH)) {
    Serial.println("[effect] wake sound failed");
    audio.stopSong();
    audio.setVolume(currentVolume);
    return;
  }

  unsigned long startedAt = millis();
  while (audio.isRunning() && millis() - startedAt < WAKE_EFFECT_TIMEOUT_MS) {
    audio.loop();
    drawDisplay();
    delay(1);
  }

  if (audio.isRunning()) {
    Serial.println("[effect] wake sound timeout");
  } else {
    Serial.println("[effect] wake sound done");
  }
  audio.stopSong();
  audio.setVolume(currentVolume);
}

void exitStoppedMode() {
  if (!stoppedMode) {
    return;
  }
  Serial.println("[control] leaving stopped mode");
  stoppedMode = false;
  setStatus("wifi resume");
  setAudioLine("wake...");
  drawDisplay(true);
  playWakeEffect();
  if (!connectWifi()) {
    stoppedMode = true;
    setStatus("stopped");
    setAudioLine("wifi failed");
    drawDisplay(true);
    return;
  }
  startAudio();
}

bool wakeIfStopped() {
  if (!stoppedMode) {
    return false;
  }
  exitStoppedMode();
  return true;
}

void setVolume(uint8_t volume) {
  currentVolume = constrain(volume, AUDIO_VOLUME_MIN, AUDIO_VOLUME_MAX);
  if (!stoppedMode) {
    audio.setVolume(currentVolume);
  }
  Serial.printf("[volume] %u\n", currentVolume);
  drawDisplay(true);
}

void pollRotary() {
  int clk = digitalRead(ROTARY_CLK_PIN);
  if (clk != lastRotaryClk && clk == LOW) {
    if (wakeIfStopped()) {
      lastRotaryClk = clk;
      return;
    }
    int dt = digitalRead(ROTARY_DT_PIN);
    if (dt != clk && currentVolume < AUDIO_VOLUME_MAX) {
      setVolume(currentVolume + 1);
    } else if (dt == clk && currentVolume > AUDIO_VOLUME_MIN) {
      setVolume(currentVolume - 1);
    }
  }
  lastRotaryClk = clk;

  bool buttonPressed = digitalRead(ROTARY_SW_PIN) == LOW;
  unsigned long now = millis();

  if (buttonPressed && !buttonWasPressed) {
    buttonWasPressed = true;
    longPressHandled = false;
    buttonPressedAt = now;
  }

  if (buttonPressed && !longPressHandled && now - buttonPressedAt >= BUTTON_LONG_PRESS_MS) {
    longPressHandled = true;
    lastButtonAt = now;
    if (stoppedMode) {
      exitStoppedMode();
    } else {
      enterStoppedMode();
    }
  }

  if (!buttonPressed && buttonWasPressed) {
    buttonWasPressed = false;
    if (!longPressHandled && now - lastButtonAt > BUTTON_DEBOUNCE_MS) {
      lastButtonAt = now;
      if (wakeIfStopped()) {
        return;
      }
      changeStation(1);
    }
  }
}

void maybeRetryAudio() {
  if (stoppedMode || !stations[currentStation].enabled) {
    return;
  }
  if (audio.isRunning()) {
    if (!streamWasRunning) {
      setAudioLine("stream ok");
      streamWasRunning = true;
    }
    lastStreamOkAt = millis();
    return;
  }
  if (streamWasRunning && millis() - lastStreamOkAt > AUDIO_RUNNING_GRACE_MS) {
    setAudioLine("stream lost");
    streamWasRunning = false;
  }
  if (millis() - lastAudioRetryAt < AUDIO_RETRY_MS) {
    return;
  }
  setStatus("audio retry");
  startAudio();
}

void myAudioInfo(Audio::msg_t msg) {
  Serial.printf("[%s] %s\n", msg.s, msg.msg);
  if (strcmp(msg.s, "info") == 0 && strstr(msg.msg, "stream ready") != nullptr) {
    audioLine = "stream ok";
    lastStreamOkAt = millis();
    streamWasRunning = true;
  } else if (strcmp(msg.s, "station_name") == 0 || strcmp(msg.s, "streamtitle") == 0) {
    audioLine = "stream ok";
    lastStreamOkAt = millis();
  }
}

}  // namespace

void setup() {
  Serial.begin(115200);
  maybeRestartAfterPowerSettle();

  Audio::audio_info_callback = myAudioInfo;
  pinMode(ROTARY_CLK_PIN, INPUT_PULLUP);
  pinMode(ROTARY_DT_PIN, INPUT_PULLUP);
  pinMode(ROTARY_SW_PIN, INPUT_PULLUP);
  lastRotaryClk = digitalRead(ROTARY_CLK_PIN);
  pinMode(BATTERY_ADC_PIN, INPUT);
  analogSetPinAttenuation(BATTERY_ADC_PIN, ADC_11db);
  setupOled();
  delay(250);
  readBattery(true);

  printBoardInfo();
  audio.setPinout(I2S_BCLK_PIN, I2S_LRC_PIN, I2S_DOUT_PIN);
  audio.setVolume(currentVolume);
  audio.setConnectionTimeout(AUDIO_CONNECT_TIMEOUT_MS, AUDIO_CONNECT_TIMEOUT_SSL_MS);
  Serial.printf("[audio] connect timeout plain=%u ssl=%u\n", AUDIO_CONNECT_TIMEOUT_MS, AUDIO_CONNECT_TIMEOUT_SSL_MS);
  setupEffects();

  if (!connectWifi()) {
    setStatus("wifi failed");
    drawDisplay(true);
    Serial.println("[wifi] no connection; restarting in 10 seconds");
    delay(10000);
    ESP.restart();
  }

  startAudio();
}

void loop() {
  if (!stoppedMode) {
    audio.loop();
  }
  pollRotary();
  maybeRetryAudio();
  readBattery();
  maybeRetryOled();
  drawDisplay();
}

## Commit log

2026-05-29 Initial esp32 radio research docs
2026-06-01 Document ESP32-S3 board photos
2026-06-01 Add initial ESP32 radio firmware
2026-06-01 Record ESP32 radio working milestone
2026-06-01 Stabilize radio station list after live tests
    [main.cpp]
2026-06-01 Add ESP32 radio audio quality notes
2026-06-06 Update ESP32 radio wake sound and enclosure docs
    [TOKYO系esp32_radio_low_profile_front_shell.3mf, esp32_radio_compact.scad, esp32_radio_low_profile_back_cover.stl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]
2026-06-09 Update ESP32 radio Wi-Fi and enclosure work
    [esp32_radio_low_profile_front_shell.stl, esp32_radio_low_profile_integrated.scad]
